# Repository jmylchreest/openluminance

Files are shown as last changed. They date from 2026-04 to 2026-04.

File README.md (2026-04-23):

# openluminance

Modular, magnetically-attached LED tiles with per-tile MCUs on a shared bus. Firmware, hardware, mechanical models, and docs live together in this repo.

**Status:** v1 design committed; 4-tile bench prototype is the next step. See [`prototypes/4-tile-bench/`](prototypes/4-tile-bench/).

---

## Concept

A master controller talks to every tile on an RS-485 bus. Each tile carries its own MCU, a small cluster of RGBW LEDs, a local buck converter, and an 8-pin palindromic edge connector so it can be rotated and still mate. The master enumerates tiles via a 1-Wire-style UID search, then pushes per-tile pixel data and broadcasts a synchronous latch.

Committed v1 decisions:

- **Per-tile MCU:** CH32V003F4P6 (32-bit RISC-V, TSSOP-20, ~£0.12, 64-bit UID baked in).
- **Bus:** RS-485 half-duplex at 1 Mbps (headroom to 10 Mbps). Linear / serpentine chain.
- **Power:** 24 V backbone chained through edge connectors, per-tile buck to 5 V. Self-correcting under voltage sag.
- **Edge connector:** 8-pin palindromic (`GND V+ A B B A V+ GND`) — any orientation mates, every signal has a redundant pin.
- **Master:** ESP32-C3 + MAX485, exposes a web UI and serves frames to the chain.

Full rationale and math in [`docs/architecture.md`](docs/architecture.md). Bench-prototype electrical schematic in [`prototypes/4-tile-bench/schematic.md`](prototypes/4-tile-bench/schematic.md).

## Repo layout

```
firmware/
  tile/            CH32V003 firmware (per tile)
  master/          ESP32-C3 master firmware
hardware/
  tile/            KiCad project for the tile PCB
  master/          KiCad project for the master board
mechanical/
  openscad/        Parametric tile enclosure, diffuser, alignment features
  stl/             Exported STLs for printing
prototypes/
  4-tile-bench/    First physical prototype — schematic, parts list, bring-up plan
docs/
  architecture.md  Bus, power, addressing, edge connector
  bom.md           Per-tile and per-system BOM
  open-questions.md Open risks and unsettled decisions
  references.md    Prior art and reference projects
thirdparty/        Git submodules for external libraries (OpenSCAD, etc.)
```

## Open questions (live)

Tracked in [`docs/open-questions.md`](docs/open-questions.md). Headline items still open:

- Edge connector physical form (pin header vs pogo strip vs mezzanine).
- Mechanical alignment tolerance on FDM PETG parts.
- Firmware update path over the bus.
- Inrush current when hot-plugging a chain of 32+ tiles at 24 V.

## Prior art

- [rmingon/led-wall](https://github.com/rmingon/led-wall) — CH32V003F*P6 + 8-bit parallel bus via 1×14 edge headers. Closest reference; hardcodes tile addresses.
- [Modular LED Wall with CH32V006 RISC-V Slave Tiles (Hackaday.io)](https://hackaday.io/project/203942-modular-led-wall-with-ch32v006-risc-v-slave-tiles)
- [CH32V003 64-bit UID read](https://pallavaggarwal.in/2023/09/25/ch32v003-programming-read-unique-id/)

## License

TBD — expected MIT for firmware/software, CERN-OHL-S for hardware, CC-BY-SA for mechanical models. Will be finalised before first release.

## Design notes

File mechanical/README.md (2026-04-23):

# mechanical/

Parametric tile enclosures, diffusers, and alignment features.

- [`openscad/`](openscad/README.md) — source `.scad` files with a preview render. Standalone; submodules in [`thirdparty/`](../thirdparty/README.md) available when needed.
- `stl/` — canonical exported STLs checked in for the current release. Iterative exports are gitignored.

Current state: **draft v0 tile model in [`openscad/tile.scad`](openscad/tile.scad)** — 100 × 100 × 15 mm single-piece enclosure. See [`openscad/README.md`](openscad/README.md) for design notes, parameters, and TODOs.

Target print material is PETG or translucent PLA. Print orientation: diffuser face down on the build plate.

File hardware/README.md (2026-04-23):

# hardware/

KiCad projects for the tile PCB and the master/bus-driver board. Empty until the bus design is frozen — see [`docs/architecture.md`](../docs/architecture.md).

- `tile/` — per-tile PCB: CH32V003, LED cluster, edge connectors, polyfuse.
- `master/` — ESP32 master or bus-driver bridge.

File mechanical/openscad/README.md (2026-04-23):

# mechanical/openscad

Parametric OpenSCAD models for the tile enclosure and associated parts.

## Files

| File | Description |
|---|---|
| [`tile.scad`](tile.scad) | Tile enclosure, draft v0. 100 × 100 × 15 mm, single-piece FDM print. |
| [`tile-preview.png`](tile-preview.png) | Rendered preview of `tile.scad` with default parameters. |

## Building

Requires OpenSCAD 2021.01 or newer.

```bash
# Render an STL for printing
openscad -o tile.stl tile.scad

# Render a preview PNG
openscad -o tile-preview.png --imgsize=1200,900 \
    --camera=50,50,7,60,0,30,400 \
    --colorscheme=Tomorrow tile.scad
```

## `tile.scad` — design notes

### Assembly structure — two printed parts (plus optional light guide)

| Part | What it is | Interchangeable? |
|---|---|---|
| **Frame** | Main body — closed back + vents, walls, edge-magnet bosses, pogo pin holes, **9 LED module cradles in a 3 × 3 grid**, **MCU dev-board retention pocket** in one corner. 100 × 100 × 13.5 mm. | No |
| **Diffuser** | 100 × 100 × 1.5 mm panel covering the entire front edge-to-edge, continuous rim press-fit into the frame opening. | **Yes** — swap for different diffusion patterns |

There is **no custom PCB** in the v1 tile. All electronics are pre-made drop-ins: 9 × SK6812 LED modules (15 × 15 mm each) slot into the cradles, and a pre-made MCU dev board (XIAO ESP32-C3, CH32V003 breakout, etc.) slides into the retention pocket. Buck + RS-485 breakout boards float in the gaps between cradles. Wiring is point-to-point with flying leads.

Render a specific part by setting `RENDER`:

```openscad
RENDER = "frame";      // or "diffuser", "assembly"
```

`assembly` shows both parts exploded along the Z axis with ghost pogo pins and colour-coded magnets — for design review, not printing.

### Print orientation

- **Frame:** closed back face down on the build plate. Walls build upward; the open front is the top of the print. Back-face vent slots print cleanly as bridged voids (first layer + in-fill around slot openings). No overhangs elsewhere.
- **Diffuser:** flat, rim side up or down either works. The rim is thin (1.2 mm) but short (3 mm) so it prints reliably in any orientation.

### How the diffuser stays on

The diffuser has a continuous rectangular rim descending from its back face that matches the frame's interior opening minus a per-side `RIM_CLEAR` (0.20 mm default). When pressed in, the rim's outer surfaces slide against the frame wall interiors along all four sides — a friction press-fit. No discrete clips to fatigue, no snap bumps, no high-stress contact points.

Assembly / service: press diffuser on from the front; to remove, insert a fingernail or plastic spudger into the `DIFF_PULL_W` (12 mm) notch cut into one edge of the diffuser and lift. The diffuser comes off clean, PCB is now accessible from the front.

| Parameter | Default | Effect |
|---|---:|---|
| `DIFFUSER_THICK` | 1.5 | Visible panel thickness |
| `RIM_DEPTH` | 3.0 | How far the rim descends into the frame |
| `RIM_T` | 1.2 | Rim wall thickness |
| `RIM_CLEAR` | 0.20 | Per-side clearance between rim outer and frame inner. **Tune this** if your printer over- or under-extrudes. Smaller = tighter; 0.05 is a very firm fit, 0.30 is loose. |
| `DIFF_PULL_W` | 12 | Finger-pry notch width |
| `DIFF_PULL_D` | 1.2 | Finger-pry notch depth |

### Coordinate system

- `z = 0` — closed back outer face (build plate when printing)
- `z = BACK_THICK` — back inner face (interior begins here)
- `z = FRAME_H` (= 13.5 mm) — top of frame walls (where diffuser rim meets the frame)
- `z = TILE_HEIGHT` (= 15 mm) — diffuser front face

Interior layout:

```
  z = 15.0  ┌─────────────── diffuser front face
  z = 13.5  ├─── diffuser back = frame wall top ───┐
                ▲                                 │
  z =  9.1  ─── ▼ LED top (SK6812 on PCB front)   │  diffuser rim
  z =  7.6  ─── PCB top face                      │  descends 3 mm
  z =  6.0  ─── PCB bottom face                   │  into frame
                ▲
  z =  2.0  ─── back inner face            ───────┘
  z =  0.0  ───────────────── back outer face (build plate)
```

### The 8-pin edge connector — all four edges populated by default

The frame cuts pogo pin holes on all four edges (`CONN_EDGES = [0, 1, 2, 3]`) so the mechanical tile is ready for v2 free-form mesh topology with no re-print. Matches the palindromic spec in [`docs/architecture.md`](../../docs/architecture.md).

```
  Reading along +X edge, low Y → high Y:
    pin 1 GND, 2 V+, 3 A, 4 B, 5 B, 6 A, 7 V+, 8 GND
```

Connector z-centre coincides with the PCB mid-plane at `CONN_Z_CENTER = 6.8`. Set `CONN_TYPE = "header"` for the bench prototype (1×8 header slot instead of individual pin holes).

### Pogo pins — short spring contacts, not deep breakouts

Tiles sit essentially wall-to-wall when mated. The pogo pins are intentionally short so the tiles don't need a gap between them — only enough length to make contact and compress ~0.5 mm per side under magnetic clamping force:

| Parameter | Default | Notes |
|---|---:|---|
| `POGO_FREE_LEN` | 5.0 mm | Uncompressed tip-to-tip |
| `POGO_COMPRESSED` | 4.0 mm | ~20 % compression when mated |
| `POGO_WALL_EXPOSE` | 0.5 mm | Tip protrusion past outer wall face at rest |
| `POGO_PIN_OD` / `POGO_FLANGE_OD` | 1.0 / 1.5 mm | Standard short-pogo format |

Sourcing: search AliExpress / LCSC for "short pogo pin 5mm 1.0mm OD" or "P50-B short spring contact". These are the same family used in pogo-pin testing jigs and magnetic breakouts.

### 24 V power rail — distributed by the PCB, not by the frame

Power is **not** a separate physical bus bar inside the frame. `V+` and `GND` pins on every populated edge tie to common `V+` / `GND` nets on the PCB — so power enters through any edge connector and exits on any other. The per-tile buck converter taps the local net.

With all four edges populated:

- **Power flows in any direction** through the tile array. No dedicated power-injection edge.
- **Chain topology on the bus** is still possible (and preferred for v1) — the PCB simply leaves `BUS_A` / `BUS_B` unrouted on 2 of the 4 edges. Frame geometry is the same.
- **v2 mesh bus** will use per-edge analogue switches (TS5A3166 or similar) under MCU control so any 2 edges can be active on the bus at a time.

### Magnets — edge-to-edge attachment

Tiles attach to adjacent tiles on the side walls. Two 5 × 2 mm neodymium discs per populated edge, offset from the edge midpoint.

| Parameter | Default | Notes |
|---|---:|---|
| `EDGE_MAGNETS` | `true` | Cut edge magnet pockets on `CONN_EDGES` |
| `EDGE_MAG_OFFSET` | 20 | mm, from edge midpoint |
| `EDGE_MAG_BOSS_D` | 3 | mm, boss extension inward from wall |
| `EDGE_MAG_Z_CENT` | 7.75 | Automatically = `(BACK_THICK + FRAME_H) / 2` |
| `MAG_CLEAR_AX` | 0.2 | Axial clearance = recess from outer face |

Pockets open outward; installed magnets recess ~0.2 mm from the tile's outer face. When two tiles mate edge-to-edge the magnet faces are separated by only ~0.4 mm of air (print clearance both sides).

**Polarity (CCW-handed rule):**

```
  +X edge   N outward at LOW Y,   S outward at HIGH Y
  +Y edge   N outward at HIGH X,  S outward at LOW X
  -X edge   N outward at HIGH Y,  S outward at LOW Y
  -Y edge   N outward at LOW X,   S outward at HIGH X
```

In `RENDER = "assembly"`, ghost magnets are colour-coded **red = N outward**, **blue = S outward**. Use this as the install reference.

### Optional back-face magnets

`BACK_MAGNETS = true` cuts four additional magnet pockets into the corner bosses, recessed from the back face. Use only if the array will stick to a ferromagnetic backplate behind the wall. Default is `false`.

### The 8-pin edge connector — matches the architecture doc

`tile.scad` models the exact palindromic 8-pin layout committed in [`docs/architecture.md`](../../docs/architecture.md). Default is `CONN_TYPE = "pogo"`, which places 8 through-holes with flange counterbores on each populated edge for double-ended pogo pins. Setting `CONN_TYPE = "header"` swaps to a single rectangular slot for a 1×8 pin header, used on the bench prototype.

Pin signal assignment (set by the PCB, not the frame — the frame is just geometry):

```
  Reading along +X edge, low Y → high Y:
    pin 1  GND
    pin 2  V+ (24 V backbone)
    pin 3  BUS_A (RS-485 A)
    pin 4  BUS_B (RS-485 B)
    pin 5  BUS_B    ← paralleled with pin 4
    pin 6  BUS_A    ← paralleled with pin 3
    pin 7  V+       ← paralleled with pin 2
    pin 8  GND      ← paralleled with pin 1
```

Palindromic. A tile flipped 180° in-plane still mates net-for-net. Every signal is carried by two pins in parallel — contact resistance halves and a single bent or oxidised pin doesn't break the link.

`CONN_EDGES` picks which edges are populated. v1 uses `[0, 2]` (= +X and −X, a linear chain). v2 sets `[0, 1, 2, 3]` and mates any edge to any edge in any orientation.

### Pogo pin spec (matches the frame cut)

Default parameters target a **double-ended spring-loaded pin, 1.0 mm OD body, 1.5 mm OD flange, 8 mm free / 5.5 mm compressed** — the common "PA1.0-8.0" format on AliExpress / LCSC. If you use a different pogo pin, update:

- `POGO_PIN_OD` — tip OD
- `POGO_PIN_HOLE` — through-hole diameter
- `POGO_FLANGE_OD` / `POGO_FLANGE_H` — flange capture counterbore
- `POGO_FREE_LEN` / `POGO_COMPRESSED` — pin length (affects tile-to-tile gap)

Render `RENDER = "assembly"` to see ghost pogo pins in their installed positions. Use this to visually verify they clear the PCB and the diffuser bay.

### Magnets — edge-to-edge attachment

Tiles attach to adjacent tiles **edge-to-edge** (not back-to-back). Edge magnets sit in the side walls of each populated edge at two positions symmetric about the edge midpoint, so that when two tiles meet along their seam the magnet faces press against each other through a thin sliver of plastic.

**Edge magnet geometry** (default 5 × 2 mm N42 neodymium discs):

| Parameter | Default | Notes |
|---|---:|---|
| `EDGE_MAGNETS` | `true` | Cut edge magnet pockets on `CONN_EDGES` |
| `EDGE_MAG_OFFSET` | 20 | mm, magnet centre from edge midpoint (one above, one below) |
| `EDGE_MAG_BOSS_D` | 3 | mm, how far the interior reinforcement boss sticks in from the wall |
| `EDGE_MAG_BOSS_W` | 9 | mm, Y-extent of each boss (> MAG_OD for margin) |
| `EDGE_MAG_BOSS_H` | 8 | mm, Z-extent (only in the back half of the tile, so PCB doesn't need cutouts) |
| `MAG_OD` | 5 | Magnet OD |
| `MAG_H` | 2 | Magnet thickness |
| `MAG_CLEAR_RAD` | 0.15 | Radial print clearance per side |
| `MAG_CLEAR_AX` | 0.2 | Axial clearance — also the recess from the outer face |

Pockets open **outward** so magnet faces are separated by only ~0.4 mm of print-clearance air when two tiles meet (MAG_CLEAR_AX × 2). Holding force is close to the "magnets touching" maximum. Plenty of boss material behind the pocket floor for structural strength.

**Polarity — use the CCW-handed pattern:**

```
Traversing edges counter-clockwise around the tile:
   +X edge    N outward at LOW Y,   S outward at HIGH Y
   +Y edge    N outward at HIGH X,  S outward at LOW X
   -X edge    N outward at HIGH Y,  S outward at LOW Y
   -Y edge    N outward at LOW X,   S outward at HIGH X
```

With this rule, any edge pair mating in any orientation pairs N↔S automatically. A 180° in-plane rotation of one tile swaps the magnet positions but also swaps the polarities on each edge, so mating still works.

In the `RENDER = "assembly"` view, ghost magnets are colour-coded: **red = N outward**, **blue = S outward**. Use this as an install reference.

### Optional back-face magnets

`BACK_MAGNETS = true` turns on the original back-face magnet pockets — one per corner boss, recessed from the back face. Use these **only** if you want the assembled tile to stick to a ferromagnetic backplate behind the wall (e.g. a steel sheet). They are **not required** for normal operation; edge magnets hold adjacent tiles together, and the array mounts to the wall via screws through the corner bosses or via a separate mounting rail. Default is `false`.

### Diffuser retention

Four clips on the frame interior (two per long wall) protrude 0.8 mm into the diffuser bay. The diffuser snaps past them during install and is held against the lip above. A 12 mm finger-pull slot on one edge of the diffuser lets it be popped out with a fingernail or spudger when swapping variants.

### Frequently-tweaked parameters

| Parameter | Default | Effect |
|---|---:|---|
| `TILE_SIZE` | 100 | Square footprint |
| `TILE_HEIGHT` | 15 | Overall Z |
| `WALL_THICK` | 2 | Side walls |
| `LIP_WIDTH` | 4 | Perimeter lip that retains the diffuser (inward from walls) |
| `LIP_THICK` | 1.5 | Front lip thickness (visible perimeter frame) |
| `DIFFUSER_THICK` | 1.5 | Diffuser panel thickness |
| `PCB_BAY_D` | 4 | Gap between diffuser back and PCB top — LED height budget |
| `BACK_CAP_THICK` | 2 | Rear cover thickness |
| `CORNER_BOSS_XY` | 14 | Size of corner post (carries magnet + PCB screw) |
| `MAG_INSET` | 8 | Magnet pocket centre from tile corner |
| `CONN_TYPE` | `"pogo"` | `"pogo"` or `"header"` |
| `CONN_EDGES` | `[0, 2]` | Which edges are populated |

### Known issues / TODO

- **Palindromic PCB layout not yet drawn.** The SCAD file reserves the geometry; the KiCad layout in `hardware/tile/` will assign nets per the table above.
- **Pogo pin retention assumes insertion from the inside face** before the PCB is installed. If a different pin type is used (e.g. single-ended sleeve-mounted to the PCB), the frame cuts need `_pogo_one_cut` updated.
- **Inter-tile alignment dowels** are not yet modelled. Currently the mating is positioned by the pogo pin tips + corner magnets. For >4 tiles chained, a pair of 1 mm alignment posts on each edge will reduce accumulated misalignment. Reserved for v0.3.
- **Ventilation** is on the back cap only. Side-wall vents may be needed once thermals are measured on the bench.
- **No cable passthrough** for a dedicated 24 V power injection tile. A tile variant with a screw-terminal cutout is a v1 job.
- **No orientation indicator on the diffuser.** If the diffuser is directional (e.g. pixelated), add an alignment notch that matches one on the frame.

## Library availability

The [`thirdparty/`](../../thirdparty/README.md) submodules (BOSL2, NopSCADlib, Round-Anything, threadlib) are available if needed. `tile.scad` is intentionally dependency-free in v0.x for easy review. Later versions will use BOSL2 for rounded fillets and NopSCADlib's pogo pin / PCB primitives.

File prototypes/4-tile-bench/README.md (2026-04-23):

# 4-tile bench prototype

First physical prototype. Goal is to prove the v1 electrical and protocol design end-to-end on a breadboard / perfboard before committing to a PCB.

## Scope

- 4 tiles assembled, bench parts for 8 in stock (slack for failures and iteration).
- Real 24 V PSU, real RS-485 wiring between tiles.
- Linear chain topology (master → tile 1 → tile 2 → tile 3 → tile 4).
- Discovery, addressing, pixel push, full-frame latch verified.

## Contents

- [`schematic.md`](schematic.md) — electrical diagrams, netlist, component-level detail.
- [`parts-list.md`](parts-list.md) — exact part numbers with supplier references.
- [`bringup-checklist.md`](bringup-checklist.md) — step-by-step verification plan.

## Success criteria

The prototype is successful when all of these pass:

1. **Power:** 4 tiles chained, measured 24 V rail sag at tile 4 is < 0.3 V at worst-case brightness. 5 V local buck output stays within ±2 % under full LED load.
2. **Bus integrity:** RS-485 eye diagram at tile 4 is clean at 1 Mbps. Sustained zero-error packet stream for 10 minutes at 60 fps-equivalent load.
3. **Discovery:** All 4 UIDs enumerated and addressed within 1 s from cold boot. Reproducible across 10 cold starts.
4. **Frame push:** Full 4-tile frame (25 RGBW pixels each) delivered and latched in < 20 ms. No visible tearing between tiles during animation.
5. **Fault tolerance:** Shorting the 5 V output on one tile (simulated LED short) blows only that tile's polyfuse; the other three continue operating.
6. **Thermal:** Tiles at full white for 30 minutes stay below 60 °C surface temperature with passive convection.

Failures on any of these invalidate the design assumption and must be resolved before PCB order.

## What this prototype does NOT test

- Mechanical edge connector (bench uses flying leads; connector choice is tested separately).
- Final PCB routing and ground-pour EMI.
- Scaling beyond 4 tiles (covered later with a 16-tile run on PCB).
- Free-form mesh v2.

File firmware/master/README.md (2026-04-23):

# firmware/master

Master controller firmware (ESP32).

Not yet implemented. Target responsibilities:

- Discover tiles on the bus, assign addresses, collect UIDs
- Hold the topology map (manual in v1, neighbour-derived in v2)
- Accept frame data from upstream (custom API, WLED integration, or DDP/E1.31 bridge)
- Slice frames into per-tile pixel payloads and push them over the bus
- Serve a web UI for manual tile placement and system control

Framework TBD. Likely ESP-IDF or Arduino-ESP32 depending on whether we fork WLED or build fresh.

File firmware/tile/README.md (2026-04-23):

# firmware/tile

Per-tile firmware for the CH32V003.

Not yet implemented. Target responsibilities:

- Read 64-bit UID at boot
- Listen on the bus for addressed packets (SOF / ADDR / CMD / LEN / PAYLOAD / CRC8)
- Respond to discovery broadcasts
- Drive the local LED strip
- Report neighbour-pin state on request (v2)

Toolchain target: [ch32v003fun](https://github.com/cnlohr/ch32v003fun) or PlatformIO with the CH32V platform. Decide once the bus design is frozen.

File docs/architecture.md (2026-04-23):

# Architecture — v1

This is the committed v1 direction. The original 8-bit-parallel sketch is retained in the appendix for context. v2 (free-form 2D mesh) is deferred — see [`open-questions.md`](open-questions.md).

## Summary

- **Topology:** linear / serpentine chain (tiles connect on two opposing edges).
- **Signal bus:** RS-485 multidrop, half-duplex, 1 Mbps (headroom to 10 Mbps).
- **Power backbone:** 24 V DC, chained through connectors, regulated locally on each tile.
- **Per-tile MCU:** CH32V003F4P6 (TSSOP-20).
- **LEDs:** 25 × SK6812 RGBW per tile, 5 V, driven from the local buck output.
- **Discovery:** UID-based enumeration using a 1-Wire-style binary-tree search, adapted for RS-485.
- **Master:** ESP32-C3 with an RS-485 transceiver; web UI holds the tile map.

## System block diagram

```
  24V PSU
     │
     ▼
┌────────────┐    ┌───────┐    ┌───────┐          ┌───────┐
│  MASTER    │────│ Tile  │────│ Tile  │── ... ──│ Tile  │
│ ESP32-C3   │    │   1   │    │   2   │          │   N   │
│ + MAX485   │    └───────┘    └───────┘          └───────┘
│ + 120Ω     │                                     + 120Ω
│   term     │                                    (end term)
└────────────┘
     │
     ▼
    Wi-Fi / Web UI
```

Master and the last tile are the two RS-485 bus endpoints; both carry 120 Ω termination. Middle tiles leave termination unpopulated. Power and signal share the same edge connectors.

## Why this stack (vs. the original parallel-bus sketch)

| Concern | Parallel bus (original) | RS-485 + 24 V (this) |
|---|---|---|
| Pins per edge | 14 | **8 (palindromic, redundant)** |
| Signal integrity over chained connectors | Poor (skew, reflections) | **Excellent (differential, proven at DMX scale)** |
| Power distribution | 5 V chained → unusable past ~4 tiles | **24 V chained, local buck — scales to 32+ tiles** |
| Protocol maturity | Novel / hand-rolled | **RS-485 is 40+ years proven, DMX is literally this** |
| Auto-addressing | Unproven on parallel bus | **1-Wire binary search adapted — well-understood** |
| Bill of materials | Underestimated pogo pin cost | Realistic, slightly higher per tile but viable |
| EMI | Significant (48 MHz parallel across gaps) | Low (differential, slow edges) |

## Edge connector — 8-pin palindromic

Pinout reads identically forwards and backwards. This means any two edges mate correctly in either relative orientation — a tile can be flipped end-for-end in-plane and still connect. Every signal is carried by two pins in parallel, so contact resistance halves and single-pin failures don't break the link.

| Pin | Name | Purpose |
|---:|---|---|
| 1 | GND | Return |
| 2 | V+ | 24 V backbone |
| 3 | BUS_A | RS-485 differential A |
| 4 | BUS_B | RS-485 differential B |
| 5 | BUS_B | RS-485 differential B (paralleled — same net as pin 4) |
| 6 | BUS_A | RS-485 differential A (paralleled — same net as pin 3) |
| 7 | V+ | 24 V backbone (paralleled — same net as pin 2) |
| 8 | GND | Return (paralleled — same net as pin 1) |

Pass-through on the tile: `V+` and `GND` wire straight across from one edge connector to the other — no series element — so downstream tiles get full rail. The local circuit taps via a polyfuse into the buck converter. Both edges share the same `BUS_A` and `BUS_B` nets (RS-485 multidrop).

### Rotational invariance — v1 vs v2

- **v1:** populate this 8-pin connector on the two chain edges only. Gives 180° in-plane flip tolerance for chain mating. Leave the other two edges unpopulated.
- **v2:** populate the same 8-pin connector on all four edges, all wired to the same V+/GND/BUS nets. Now any tile can mate any other tile on any edge in any orientation, BUT the bus becomes a mesh — need per-edge analogue switches (e.g. TS5A3166) selected by the MCU so only two edges are electrically active on the bus at any time. **Mechanical connector is identical between v1 and v2**, so v2 upgrade is a firmware-plus-populate change, no PCB redesign.

Face-flip (LEDs pointing at the wall) is prevented mechanically — magnet polarity + asymmetric alignment dowels on the back face only.

## Per-tile electrical overview

```
                            ┌──────────────────────────────────┐
  LEFT EDGE                  │              TILE               │        RIGHT EDGE
  CONNECTOR                  │                                 │        CONNECTOR
                             │                                 │
  V+ ──────┬──────────────── pass-through rail ─────────────────┬──── V+
  GND ─────┼──────────────── pass-through rail ─────────────────┼──── GND
           │                 │                                 │      │
           │  ┌──────────────┴─────┐                           │      │
           │  │ Polyfuse (0.5A)    │                           │      │
           │  │ → P-MOSFET (rev)   │                           │      │
           │  │ → TVS diode        │                           │      │
           │  │ → Buck (24→5V, 2A) │                           │      │
           │  └────────┬───────────┘                           │      │
           │           │ 5V                                    │      │
           │           ├────────────────┬──────────┐           │      │
           │           │                │          │           │      │
           │           ▼                ▼          ▼           │      │
           │     ┌──────────┐    ┌──────────┐  ┌─────────┐     │      │
           │     │ CH32V003 │    │  MAX485  │  │ 25× SK- │     │      │
           │     │  MCU     │────│ RS-485   │  │  6812   │     │      │
           │     │          │    │  TRX     │  │ RGBW    │     │      │
           │     └────┬─────┘    └────┬─────┘  └─────────┘     │      │
           │          │               │                        │      │
           │          │          ┌────┴────┐                   │      │
  BUS_A ───┼──────────┼──────────┤ A     B ├───────────────────┼── BUS_A
  BUS_B ───┼──────────┼──────────┤         ├───────────────────┼── BUS_B
           │          │          └─────────┘                   │      │
           │          │                                        │      │
           │          └── UART TX/RX + DE/nRE                  │      │
           │                                                   │      │
           └───────────────────────────────────────────────────┘
```

## Addressing protocol (v1)

Half-duplex RS-485. Master polls; tiles respond only when addressed or during a discovery slot.

**Discovery (binary-tree UID search)** — adapted from Dallas 1-Wire:

1. Master broadcasts `SEARCH_ROM(prefix, length)`.
2. All tiles whose 64-bit UID starts with `prefix` respond on the next bit position: `0`, `1`, or both (collision).
3. Collision → master descends one branch (say `0`), recurses.
4. When a leaf is reached, master has a unique UID → assigns it a bus address (1..254).

For N tiles this is O(N × 64) bus transactions — about 2 seconds for 32 tiles at 1 Mbps. Runs once at startup, never again unless the map is rebuilt.

**Normal operation:**

```
  Packet: 0xA5  ADDR  CMD  LEN  PAYLOAD[LEN]  CRC8
          SOF   1B    1B   1B   0..240B       1B
```

- `ADDR 0x00` = master
- `ADDR 0xFF` = broadcast
- `ADDR 0x01..0xFE` = unicast
- Commands: `PING`, `SET_PIXELS`, `LATCH`, `GET_STATUS`, `REBOOT`, `SET_ADDR` (during discovery only)

Frame flow: master sends `SET_PIXELS` to each tile in turn (75 bytes RGB × 25 pixels + overhead ≈ 80 bytes per tile → 0.8 ms per tile at 1 Mbps). Then a single `LATCH` broadcast tells everyone to update simultaneously. 32 tiles = 25.6 ms + 1 latch = ~27 ms, comfortably inside a 60 fps budget.

## Power math (why 24 V)

Per tile worst case: 9 LEDs × 60 mA @ full white = 540 mA @ 5 V = 2.7 W. 32-tile array = 86 W. (The original 25-LED design pushed 7.5 W/tile / 240 W system; the tile is a lighting element, not a pixel-addressable display, so 9 LEDs is plenty and the numbers shrink.)

At **5 V** chained: tile 1 carries 17 A. Pogo/header contacts can't carry that across many tiles without significant IR drop — LEDs go dim and off-colour down-chain.

At **24 V** chained with per-tile buck (η ≈ 85 %): tile 1 carries ~4.3 A across the whole 32-tile chain, drop per hop ≈ 0.1 V. Buck compensates by drawing slightly more current as input sags. **Self-correcting**.

System PSU: 24 V, **≥5 A** for 32 tiles (with margin). Mean Well LRS-100-24 or equivalent (~£15).

## Components per tile (high level)

| Function | Part | Est. £ (vol) |
|---|---|---:|
| MCU | CH32V003F4P6 (TSSOP-20) | 0.12 |
| RS-485 transceiver | MAX485 / SP485EEN / MAX3485 | 0.35 |
| Buck converter (24→5 V) | MP1584EN + L + Cs (discrete) | 0.60 |
| LEDs | 9 × SK6812 RGBW (3 × 3 grid, 30 mm pitch) | 1.53 |
| Protection | Polyfuse + TVS + rev-pol FET | 0.25 |
| Edge connectors | 2× pin header or pogo strip | 0.80 |
| PCB + passives | | 0.40 |
| Enclosure + diffuser + magnets | | 0.80 |
| **Total** | | **~£5.31** |

Detailed part numbers in [`../prototypes/4-tile-bench/parts-list.md`](../prototypes/4-tile-bench/parts-list.md).

## Appendix — discarded: 8-bit parallel bus

The original proposal used DATA0–7, CLK, EN on a 14-pin edge connector with tile addresses hardcoded in `main.c`. Discarded because: (a) signal integrity across chained connectors at 48 MHz is unpredictable, (b) pin count drives connector cost and mechanical failure rate, (c) no native arbitration means auto-addressing requires inventing a scheme, (d) EMI risk for any future compliance work. The reference project ([rmingon/led-wall](https://github.com/rmingon/led-wall)) is a working existence proof of that architecture at small scale but does not auto-address. RS-485 gives us equivalent or better bandwidth with 6 pins, proven protocol stacks, and off-the-shelf transceivers.

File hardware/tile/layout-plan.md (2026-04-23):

# Tile PCB layout plan

How the LED array, MCU, buck, transceiver, and supporting components fit inside the 100 × 100 × 15 mm enclosure. Companion to [`../../mechanical/openscad/tile.scad`](../../mechanical/openscad/tile.scad) and [`../../docs/architecture.md`](../../docs/architecture.md). Drives the KiCad board outline before the first schematic spin.

## Topology: no custom PCB — drop-in modules + pre-made dev board

**Nothing is custom-fabricated.** Nine individual pre-made SK6812 LED modules drop into 9 cradles printed into the frame interior at the 3 × 3 grid positions. A pre-made MCU dev board (XIAO ESP32-C3, CH32V003 breakout, or equivalent) slides into a retention-rib pocket in the −X, −Y corner of the frame. Short point-to-point wires connect the dev board to each LED module (data chain + power) and to each edge-connector group. No custom PCB; no central board; no corner screw bosses.

```
   ┌──────────────────────────────┐ ← diffuser (100 × 100, edge-to-edge)
   │                              │
   │                              │
   │  (LED) (LED) (LED)           │ ← 9 × SK6812 modules in 3 × 3 cradles
   │                              │     on 30 mm pitch, printed into frame
   │  (LED) (LED) (LED)           │
   │                              │
   │  (LED) (LED) (LED)           │
   │                              │
   ├──────────────────────────────┤
   │ [dev brd]                    │ ← MCU dev board in its corner pocket,
   │                              │     retained by printed rib clips.
   │                              │     Wires fan out to LED cradles and
   │                              │     to the edge connector groups.
   ├──────────────────────────────┤ ← frame back inner face
   │     vvv     vvv     vvv      │ ← vent slots
   └──────────────────────────────┘ ← frame back outer face
```

### Why no PCB

- **Lower iteration cost.** No board spin, no JLCPCB wait time. Pick a different MCU next week — swap the dev board.
- **No SMT assembly.** All parts come pre-assembled. Per-tile build is soldering wires to header pins.
- **Simpler v1 bench.** Any CH32V003 dev board + MP1584 buck module + MAX485 breakout wired together works; or a XIAO ESP32-C3 on its own if you're willing to take the WiFi-per-tile path.
- **Repairability.** Dead LED? Pop the diffuser, pull the module, plug in a new one. Dead MCU? Slide the dev board out of its pocket and replace.

### Trade-off

Per-tile assembly is **slower and more expensive** than a custom PCB would be (~£18 + ~30 min of wiring vs ~£5 + 10 min of click-and-solder). This is the right choice for exploratory v1 bench hardware, not for a production run — at volume, collapse back into a custom PCB.

## Space budget — what's actually available

### Z stack (15 mm total, 11.5 mm interior)

```
  z = 15.0 ────────── diffuser front face ──────────
  z = 13.5 ────────── frame walls top / diffuser back
                 ↑
                 │ 4.4 mm diffusion gap (air)
                 ↓
  z =  9.1 ────────── LED top (SK6812 body 1.5 mm above PCB)
  z =  7.6 ────────── PCB top face ──── [ 9 × SK6812 in 3×3 grid ]
  z =  6.0 ────────── PCB bottom face ── [ MCU, buck, transceiver, passives ]
                 ↑
                 │ 4.0 mm back-side component space
                 ↓
  z =  2.0 ────────── back inner face
  z =  0.0 ────────── back outer face (ventilation slots)
```

**Tight constraint: the 4 mm back-side space.** Any component taller than 4 mm doesn't fit. This rules out standard radial electrolytic caps (~11 mm tall) and some through-hole inductors. See [BOM constraints](#component-height-constraints) below.

### Plan view — 100 × 100 mm interior features

Features that cut into the 96 × 96 mm usable interior footprint:

| Feature | Footprint | Qty | Area | Notes |
|---|---|---:|---:|---|
| LED module cradles | 17.4 × 17.4 mm | 9 | 2725 mm² | 15 × 15 mm module bay with 1.2 mm lip, z = 2 → 6 |
| MCU board pocket (floor + ribs) | 26 × 20 mm | 1 | 520 mm² | Corner at (3, 3) with rib clips on ±Y sides |
| Edge magnet bosses | 9 × 3 mm | 8 | 216 mm² | 2 per edge × 4 edges |
| Pogo pin retainers | 22 × 2 mm | 4 | 176 mm² | 1 strip per edge, centred |
| **Total feature area** | | | **~3640 mm²** | out of 9 216 mm² interior |

There's no longer a PCB footprint to negotiate — all these features are just printed plastic that the modules/board drop into. Remaining interior volume is for wire routing.

## Layout — plan view

No board outline to draw — the features are printed directly into the frame. Plan view (not to scale):

```
           -Y edge
           ▼
  ┌──────────────────────────────┐ ← 100 mm tile outer edge
  │                              │
  │ [MCU]                        │
  │ pocket    ┌─┐  ┌─┐  ┌─┐      │   3 × 3 LED cradles (17.4 mm each)
  │ (26×20)   └─┘  └─┘  └─┘      │   centred at tile-local
  │           ┌─┐  ┌─┐  ┌─┐      │   (20, 20), (50, 20), (80, 20),
  │           └─┘  └─┘  └─┘      │   (20, 50), (50, 50), (80, 50),
  │           ┌─┐  ┌─┐  ┌─┐      │   (20, 80), (50, 80), (80, 80)
  │           └─┘  └─┘  └─┘      │
  │                              │
  └──────────────────────────────┘
```

### LED cradle dimensions

Each cradle is a 17.4 × 17.4 mm printed plinth with a 1.2 mm lip around the top. The 15 × 15 × 1.6 mm LED module drops into the centre recess (friction fit, no glue). A 3 mm wire-exit slot on the −Y face of each cradle lets the pigtail escape to the harness.

Typical SK6812 single-LED module footprints (confirm before buying):

| Source | Outer size | Notes |
|---|---|---|
| BTF-Lighting individual SK6812 PCB | ~15 × 15 mm | Solder pads on all 4 sides |
| Adafruit NeoPixel single (1558) | ~8 × 10 mm | Smaller; would need adapter plate or smaller cradle |
| Custom bare SK6812 5050 on a 15 × 15 breakout | 15 × 15 mm | ~£0.15 at JLCPCB with 500 MOQ — still no *per-tile* custom board, just a reusable sub-module |

If your modules are smaller than 15 × 15, reduce `LED_MOD_XY` in `tile.scad`; the cradle auto-sizes.

### MCU board pocket

Floor at the frame back inner face, in the −X, −Y corner. Two parallel printed ribs (1.2 mm × 3 mm tall) retain the board by clamping its long sides. Works for any board up to 24 × 18 mm or so — covers the common dev boards:

| Board | Size | Notes |
|---|---|---|
| Seeed XIAO ESP32-C3 | 21 × 17.5 mm | USB-C, WiFi + BT. Overkill but plug-and-play |
| Seeed XIAO RP2040 / RP2350 | 21 × 17.5 mm | No WiFi, great for RS-485 node |
| CH32V003F4P6 bare breakout (hand-made or LCSC) | ~20 × 15 mm | Matches the committed architecture |
| RP2040-Zero | 23 × 18 mm | Cheap (~£3), USB-C, loads of GPIO |

## LED grid placement

**Nine** SK6812 RGBW modules at 30 mm pitch, centred in the tile: positions (20, 20), (50, 20), (80, 20), (20, 50), (50, 50), (80, 50), (20, 80), (50, 80), (80, 80). Each module sits in its own printed cradle; the centre cradle also acts as a thermal conduit from the centre LED down into the frame back.

Data chain: WS2812-style serpentine — row 0 left→right, row 1 right→left, row 2 left→right. DIN of LED (20, 20) from MCU (e.g. ESP32-C3 GPIO0); DOUT of LED (80, 80) terminated at a header pin on the MCU board for debug.

### Why 9, not 25

Each tile is **one colour cell in the system**, not a pixel-addressable display. Nine SK6812 RGBW at 60 mA = ~540 mA @ 5 V = 2.7 W peak per tile, ~45 lumens of diffused ambient output. The diffuser blends them into a single uniform glow (or 9 distinct pixels if the optional light guide is fitted). Going to 25 triples the power, cost, and thermal load for no benefit if the tile isn't trying to draw an image.

## Controller stack per tile

Three pre-made modules wired together, sitting in the MCU pocket + routed to the edge connectors via a harness:

1. **MCU dev board** — carries the CH32V003 (or ESP32-C3, etc.) and exposes its GPIOs on 2.54 mm headers. Sits in the corner pocket.
2. **Buck converter module** — MP1584EN 24 → 5 V, ~17 × 11 × 4 mm. Pre-trimmed to 5 V output. Mounts anywhere with double-sided tape; its output supplies the dev board and LED string.
3. **RS-485 transceiver breakout** — MAX485 on a tiny carrier with header pins. ~15 × 15 mm. Wired between the MCU's USART and the BUS_A/BUS_B edge pins.

Total controller footprint: ~55 × 20 mm when laid end-to-end, plus some wiring space. Fits comfortably in the bottom half of the tile interior (between the LED cradles and the back wall), held by double-sided tape. The MCU pocket holds only the MCU board; buck and transceiver float in the interior.

### Height budget

Interior depth from back inner face (z = 2) to lowest LED cradle surface (z = 2) is 0 — the cradles *start* at the back inner face. So the buck/transceiver modules sit in the gaps between cradles, not underneath them. Max module height = cradle top − back face = 4 mm. MP1584 modules are ~4 mm including header pin stubs (trim stubs flush if necessary). RS-485 breakouts are typically 3 mm. Both fit.

Alternative: mount buck + transceiver to the inside of the back cap or the underside of the diffuser... no, neither of those is accessible. They live in the interior floor between cradles.

## LEDs are not strips

Individual SMD SK6812 5050 parts placed directly on the tile PCB, not a flexible strip. Three reasons:

1. **Pitch mismatch.** 60 LED/m strip has 16.7 mm pitch; our grid needs 20 mm. Re-cutting and re-wiring a strip to 25 segments is fragile and time-consuming.
2. **Fewer parts, fewer joints.** The PCB is already being made for the MCU and supporting circuitry. Placing 25 more LEDs on the same board is near-free at JLCPCB (~1 ¢ per placement).
3. **Thickness.** Strip form factor adds ~1 mm for the strip PCB plus adhesive plus any sleeving. The SMD LEDs sit flat on our board with no extra stack-up.

If you ever want to adapt the design to strips, the control electronics would need to split onto a separate small MCU board at one end of the strip run.

## Optional light guide

A third printable part — a 5 × 5 pixel-grid lattice — can be printed separately and dropped into the tile between the PCB and the diffuser. With it, each LED has its own 20 × 20 mm chamber with reflective walls, producing sharp distinct pixels. Without it, light blends smoothly across the diffuser.

Specs (see [`../../mechanical/openscad/tile.scad`](../../mechanical/openscad/tile.scad) — `RENDER = "light_guide"`):

- 5 × 5 grid of 20 × 20 mm cells
- Wall thickness 1.2 mm, wall height 5 mm
- Outer footprint ≈ 95 × 95 mm (sits inside the frame opening with 0.4 mm per-side clearance)
- Material: white PETG or PLA (reflective)
- No retention features — held in place by the PCB below and the diffuser rim above
- Swappable without disassembling the frame: pop the diffuser, drop the guide in, re-seat the diffuser

Print orientation: flat. Walls print as tall thin columns; use 2–3 perimeters for wall strength.

## Routing summary

High-level PCB wiring plan for the v1 (linear-chain) variant:

| Net | Where | Notes |
|---|---|---|
| `V+` (24 V) | From +X and −X edge connectors (pin 2 and pin 7) → common net → local buck input | Tie +Y and −Y V+ pads to the same net for v2 compatibility |
| `GND` | From all four edge connectors (pins 1 and 8) → common ground plane | Thick copper pour on inner layers |
| `5V` (local) | Buck output → MCU, MAX485, and the 25-LED array | Local to this tile; does not leave |
| `BUS_A` / `BUS_B` | +X edge (pins 3, 6 and 4, 5) ↔ MAX485 A/B ↔ −X edge | +Y and −Y bus pads left unconnected in v1 |
| `LED_DATA` | MCU PA1 → 330 Ω series R → DIN of first LED → DOUT→DIN chain through all 25 → final DOUT to test pad | Serpentine route |
| `UART_TX` / `UART_RX` / `DE` | MCU USART1 + one GPIO → MAX485 control pins | Keep short |

## Build constraints (for the assembly person)

- **MCU board** fits a pocket 26 × 20 mm at tile-local (3, 3) – (29, 23), retained by 1.2 mm ribs on ±Y long sides. Boards up to 24 × 18 mm work.
- **9 LED modules** drop into cradles on 30 mm pitch centred at tile-local (20, 20) through (80, 80). Each cradle bay is 15 × 15 mm with a 1.2 mm lip — pre-made 15 × 15 mm SK6812 breakouts are the target fit. Smaller modules (e.g. 8 × 10 mm) need either a smaller `LED_MOD_XY` in the SCAD or a printed adapter plate.
- **Pogo pin tips** are at z = 6.8 on every populated edge. Wire the module's edge-pad pigtails to each pin's inner tip — 32 pins per tile is a lot of hand-soldering; an edge-breakout mini-PCB (pre-made or custom) makes this tractable. Kept out of the SCAD for v1; pure flying-lead assembly works for the bench prototype.
- **Max interior component height** (for buck, transceiver, wire bundles) between the back wall and the underside of the LED cradles = 4 mm. MP1584 modules fit with trimmed header pins; RS-485 breakouts fit easily.
- **Thermal:** 9 LEDs × 60 mA @ 5 V = 2.7 W peak per tile. Passive convection via back-face vents handles this; no heat sinks or thermal grease needed.

## Open questions for the PCB design stage

- **Pogo pin mounting:** pins mounted to the frame (currently modelled) or soldered to PCB edge castellations? Choice affects PCB edge-pad vs. edge-castellation design.
- **Power injection:** do we need a dedicated tile variant with a screw-terminal 24 V input for the head of a long chain? Or inject via a custom master-adjacent tile?
- **Firmware update path:** expose SWIO via a 3-pin test pad on the back of the PCB, accessible through the back-face vent area with a pogo jig. Needs space reservation.

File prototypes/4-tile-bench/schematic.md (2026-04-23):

# Electrical Schematic — 4-tile bench

Text schematic for the bench prototype. A proper KiCad schematic will land in `hardware/tile/` before PCB order; this document captures the design the KiCad sheets should implement and is the source of truth for the bench build.

## 1. System-level

```
   ┌─────────────┐
   │  24 V PSU   │   Mean Well LRS-50-24 or equivalent
   │   (2 A +)   │
   └──┬──────┬───┘
      │ 24V  │ GND
      ▼      ▼
   ┌──────────────┐
   │   MASTER     │
   │              │
   │  ESP32-C3    │       ┌───────┐   ┌───────┐   ┌───────┐   ┌───────┐
   │  + MAX485    │──A────│       │───│       │───│       │───│       │
   │  + 120Ω term │──B────│ Tile  │───│ Tile  │───│ Tile  │───│ Tile  │
   │  + biasing   │──V+───│  #1   │───│  #2   │───│  #3   │───│  #4   │
   │  680Ω x2     │──GND──│       │───│       │───│       │───│       │
   │              │       └───────┘   └───────┘   └───────┘   └───┬───┘
   └──────┬───────┘                                                │
          │                                                  120Ω termination
          ▼                                                  between A and B
        Wi-Fi                                                  on last tile
```

Master carries the `+` end of the RS-485 bus, fixed biasing (680 Ω A→V+, 680 Ω B→GND), and one 120 Ω termination. The fourth tile carries the other 120 Ω. Middle tiles leave termination and biasing unpopulated.

## 2. Per-tile block diagram

```
        LEFT EDGE                                           RIGHT EDGE
        CONNECTOR J1                                        CONNECTOR J2
        ┌────────┐                                          ┌────────┐
 GND ───│ 1      │◄────────── pass-through rail ───────────►│  1   8 │─── GND
  V+ ───│ 2  PIN │                                          │  PIN 7 │─── V+
 A   ───│ 3  MAP │◄────────── shared bus net A ────────────►│  MAP 6 │─── A
 B   ───│ 4      │◄────────── shared bus net B ────────────►│      5 │─── B
 B   ───│ 5      │                                          │      4 │─── B
 A   ───│ 6      │                                          │      3 │─── A
  V+ ───│ 7      │                                          │      2 │─── V+
 GND ───│ 8      │                                          │      1 │─── GND
        └────────┘                                          └────────┘
            │                                                    │
            │                                                    │
            │  (V+ and GND pass straight across — no series element)
            │
            ├───────────────────────────────────────── local 24V tap
            │
            ▼
      ┌─────────────┐
      │ POLYFUSE    │ 0.5 A hold, 1 A trip
      │ (F1)        │
      └─────┬───────┘
            ▼
      ┌─────────────┐
      │ P-MOSFET    │ Reverse-polarity block
      │ (Q1)        │
      └─────┬───────┘
            ▼
      ┌─────────────┐
      │ TVS (D1)    │ SMBJ28CA bidirectional, 28 V clamp
      └─────┬───────┘
            ▼
      ┌─────────────┐
      │ 47 µF/35V   │ Bulk input cap (C1)
      │ + 100 nF    │ HF bypass (C2)
      └─────┬───────┘
            ▼
      ┌─────────────┐   L1: 22 µH shielded
      │ MP1584EN    │   D2: SS34 Schottky
      │ buck (U1)   │   R_FB: 10k / 3.16k → 5.0 V out
      │ 24V → 5V    │   C_OUT: 2× 22 µF X7R
      └─────┬───────┘
            │ 5 V local
            ├─────────────────┬───────────────────┐
            ▼                 ▼                   ▼
       ┌────────┐        ┌─────────┐      ┌──────────────┐
       │ CH32V- │        │ MAX485  │      │ 25 × SK6812  │
       │  003   │──TX───►│ DI      │      │  RGBW chain  │
       │  (U2)  │◄─RX────│ RO      │      │              │
       │        │──DE───►│ DE/RE'  │      │ DATA_IN ◄────┼── from U2 PA1
       │        │        │ A   B   │      │              │
       └────────┘        └──┬───┬──┘      └──────────────┘
                            │   │
                      SHARED BUS NET A/B
                      (tied to both J1 and J2
                       pins via identical PCB nets)
```

## 3. Power subsystem detail

```
Edge V+ (24 V) ──┬────────────────────────────────────── pass-through to other edge V+
                 │
                 ├── F1 ──┬── Q1_s     Q1 = AO3401 P-MOSFET
                 │        │            gate to GND via R_G (10k), diode-clamped
                 │        │            source faces load (blocks reverse polarity
                 │        │            and drops only ~Rds_on × I ≈ 50 mV)
                 │        │
                 │        └── drain ──┬── TVS (D1, SMBJ28CA) to GND
                 │                    │
                 │                    ├── C1 (47 µF/35 V) to GND
                 │                    │
                 │                    └── VIN of MP1584
                 │
Edge GND ────────┴────────────────────────────────────── pass-through to other edge GND

MP1584EN (U1) pinout (TSOT-23-8):
   1 BOOT  ── 10 nF to SW
   2 VIN   ── from Q1 drain
   3 EN    ── tied to VIN (always on)
   4 COMP  ── loop compensation RC (22 kΩ + 2.2 nF to GND)
   5 FB    ── 3.16 kΩ to GND, 10 kΩ to VOUT  (Vfb = 0.8 V, ratio → 5.0 V)
   6 GND
   7 SW    ── to L1 (22 µH) → VOUT node; D2 (SS34) from SW to GND
   8 VIN   ── tied to pin 2

VOUT node:
   ── 2 × 22 µF X7R (C_OUT1, C_OUT2) to GND
   ── 100 nF (C_OUT3) to GND at point of load
   ── 5 V rail to MCU, transceiver, LED cluster
```

### Power math check

| Load | I @ 5 V | Local 5 V current |
|---|---:|---:|
| CH32V003 active | ~5 mA | |
| MAX485 active | ~1 mA | |
| 25 × SK6812 RGBW at full white | ~1500 mA | |
| **Peak local load** | | **~1.51 A** |

MP1584EN is rated 3 A output — comfortable margin. Efficiency at 1.5 A load, 24 V input: ~85 % from the datasheet curves. Input current: `1.51 × 5 / 24 / 0.85 ≈ 0.37 A per tile at 24 V`.

For 8 tiles chained, worst case through tile 1's connectors: **~3 A at 24 V**, well within 2×-pin-parallel header capacity (~6 A for 0.1" headers).

## 4. RS-485 subsystem detail

```
MAX485 (U3) pinout (SOIC-8):
   1  RO   ── to CH32V003 USART1_RX (PD6)
   2  RE'  ── tied to pin 3 (half-duplex: DE and RE' always match)
   3  DE   ── from CH32V003 GPIO (PD4); HIGH = driving, LOW = receiving
   4  DI   ── from CH32V003 USART1_TX (PD5)
   5  GND
   6  A    ── to edge connector pins 3 and 6 (both edges)
   7  B    ── to edge connector pins 4 and 5 (both edges)
   8  VCC  ── 5 V

Protection and biasing (populated only on first/last tiles):
   TVS diode between A-B (SM712 or PESD1CAN, £0.15)
   120 Ω termination: resistor between A and B, placed on endpoint tiles only
   680 Ω fail-safe bias: A→V+ and B→GND, placed on master only
```

### Bus throughput budget at 1 Mbps

- 1 bit = 1 µs. UART framing: 10 bits/byte (start + 8 + stop) = 10 µs/byte.
- Per-tile packet: `SOF(1) + ADDR(1) + CMD(1) + LEN(1) + 75B payload + CRC(1) = 80 bytes = 800 µs`.
- 32 tiles × 800 µs = 25.6 ms per full frame + broadcast LATCH (~50 µs).
- **Supports ~38 fps for 32 tiles at 1 Mbps.** Bump to 2.5 Mbps (CH32V003 USART can do this) for ~96 fps.

## 5. MCU subsystem detail

CH32V003F4P6 pin assignments for v1 (TSSOP-20):

| Pin | Name | Function | Net |
|---:|---|---|---|
| 1 | PD4 | GPIO output | `RS485_DE` (driver enable, also tied to /RE) |
| 2 | PD5 | USART1_TX | `TX` → MAX485 DI |
| 3 | PD6 | USART1_RX | `RX` ← MAX485 RO |
| 4 | PD7/NRST | Reset | pulled up, test point |
| 5 | PA1 | GPIO output (TIM1 CH2 optional) | `LED_DATA` → SK6812 chain |
| 6 | PA2 | GPIO | Reserved (v2 NBR_N) |
| 7 | GND | Ground | GND |
| 8 | PC0 | GPIO | Reserved (v2 NBR_E) |
| 9 | PC1 | GPIO | Reserved (v2 NBR_S) |
| 10 | PC2 | GPIO | Reserved (v2 NBR_W) |
| 11 | PC3 | GPIO | (spare) |
| 12 | PC4 | GPIO | (spare) |
| 13 | PC5 | GPIO | (spare) |
| 14 | PC6 | GPIO | (spare) |
| 15 | PC7 | GPIO | (spare) |
| 16 | PD0 | GPIO / OSCI | (spare) |
| 17 | PD1 | SWIO | **PROGRAMMING — WCH-LinkE** (do not load) |
| 18 | PD2 | GPIO | (spare) |
| 19 | PD3 | GPIO | (spare) |
| 20 | VDD | 5 V | 5 V rail (with 100 nF + 10 µF decoupling) |

Programming header (3-pin JST-SH or test pads): 5 V, GND, SWIO (PD1). Flashed by WCH-LinkE before install; over-the-bus OTA is a v2 firmware task.

## 6. LED chain

SK6812 RGBW data line is fed from `PA1` (CH32V003) via a 330 Ω series resistor (reduces reflections on the first LED's data input). 25 LEDs in a 5×5 grid, wired in classic snake order (row 0 left-to-right, row 1 right-to-left, etc.).

Decoupling: 100 nF per LED is overkill but good practice — budget allows. Minimum: one 10 µF bulk cap + 100 nF every 5 LEDs.

Absolute max current with all LEDs full white: 25 × 60 mA = 1.5 A. Buck is sized for 2 A → 25 % margin. If the user-facing brightness cap is set to 80 %, continuous worst case drops to 1.2 A.

## 7. Master module

```
ESP32-C3 (e.g. XIAO ESP32-C3 dev board):
   3V3  ─── from onboard USB/LDO
   GND  ─── shared with 24 V PSU GND!!  ← critical
   GPIO0 ── UART0 TX ─► MAX485 DI
   GPIO1 ── UART0 RX ─◄ MAX485 RO
   GPIO2 ── GPIO ────► MAX485 DE (tied to /RE)

MAX485 (master side, SOIC-8):
   VCC   ─── 5 V (can derive from USB or step-up from 3.3 V; 3.3 V-tolerant variants exist — check datasheet)
   A     ─── to bus A, via 120 Ω termination to B
                            and 680 Ω bias to V+
   B     ─── to bus B, via 680 Ω bias to GND

Master 24 V → tile chain V+: wired directly (PSU feeds the chain, master logic
powered from USB — separate rail for clean operation during firmware work).
```

**Critical:** master GND and 24 V PSU GND must be **the same net**. If not, the RS-485 common-mode reference is undefined and you'll get intermittent bit errors.

## 8. Consolidated netlist (per tile)

For reference when laying out the PCB.

```
NET V24        J1.2, J1.7, J2.2, J2.7, F1.1, (no decoupling — pass-through)
NET V24_LOCAL  F1.2, Q1.source
NET V24_FUSED  Q1.drain, D1.+, C1.+, U1.2 (VIN), U1.8 (VIN)
NET SW         U1.7, L1.a, D2.cathode
NET V5         L1.b, D2.anode_NO (Schottky anode = GND side), C_OUT1+, C_OUT2+, U1.5 via feedback divider, U2.20 (VDD), U3.8 (VCC), LED[0].VCC..LED[24].VCC
NET GND        J1.1, J1.8, J2.1, J2.8, D1.-, C1.-, U1.6, D2.anode (SS34 cathode = SW, anode = GND), C_OUT*.-, R_FB_lo, U2.7 (GND), U3.5 (GND), LED[*].GND
NET BUS_A      J1.3, J1.6, J2.3, J2.6, U3.6 (A)
NET BUS_B      J1.4, J1.5, J2.4, J2.5, U3.7 (B)
NET UART_TX    U2.2 (PD5), U3.4 (DI)
NET UART_RX    U2.3 (PD6), U3.1 (RO)
NET RS485_DE   U2.1 (PD4), U3.2 (RE'), U3.3 (DE)
NET LED_DATA   U2.5 (PA1), R_SERIES, LED[0].DIN
```

(`LED[i]` is the i-th SK6812 in the chain; DOUT of each connects to DIN of the next.)

## Open electrical questions

- **Ground pour under buck switch node** — keep SW node area minimised; pour under VOUT only. Will be addressed in PCB layout.
- **ESD on edge connector pins** — TVS on bus already specced; V+ and GND pins see transients too. Consider TVS arrays on all four pins of the connector in the PCB version.
- **Brown-out on master when chain is live-connected** — inrush from C1 (47 µF × 32 tiles = 1.5 mF) at 24 V is severe. Add NTC inrush limiter at the PSU or soft-start resistor on the first tile's polyfuse branch.

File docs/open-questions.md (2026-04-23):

# Open Questions and Risks

Live list of things we don't yet know or haven't decided. Resolve and remove items as they close out. See also the closed/settled list at the bottom.

## Must resolve before PCB order

- [ ] **Edge connector physical form.** 1×8 pin header + socket (cheap, proven, one mating direction) vs spring pogo strips (lower profile, more mating cycles, needs tighter alignment) vs Amphenol/Molex mezzanine (rigid, expensive). Target: decide from 4-tile bench test data.
- [ ] **Mechanical alignment feature.** FDM printing tolerance on PETG is ±0.3 mm. Need dowel+pocket, keyed edges, or machined inserts.
- [ ] **Bus termination strategy.** Fixed at endpoints (simple, but endpoints must be known) vs switchable per-tile (complex, but any tile can be the endpoint). v1: fixed, master + designated "terminator" tile at far end.
- [ ] **Bus biasing.** RS-485 idle-state biasing (680 Ω to V+ on A, 680 Ω to GND on B). Populated on master only, or on first tile?

## Must resolve before firmware v1

- [ ] **Discovery timing.** Implement the 1-Wire-style binary-tree UID search on RS-485 and measure. Expected ~2 s for 32 tiles at 1 Mbps.
- [ ] **Frame synchronisation mechanism.** Proposed: master sends per-tile `SET_PIXELS`, then a broadcast `LATCH` command. Verify timing jitter across tiles under worst-case load.
- [ ] **Firmware update path.** Field-updatable tiles? Over the bus, or only via WCH-LinkE programmer? Bus-based firmware update is non-trivial with only 16 KB flash (bootloader budget).

## Must resolve before calling it done

- [ ] **Thermal.** 25 SK6812 at full white ≈ 7.5 W per tile. Diffuser standoff, vent pattern, and/or a global brightness cap in firmware.
- [ ] **EMI.** Differential RS-485 + 24 V linear power drop is low-risk, but buck switching noise needs measurement if CE/FCC is ever a goal.
- [ ] **License.** MIT / CERN-OHL-S / CC-BY-SA or something else.
- [ ] **v2 scope.** Commit to v2 (4-edge mesh, palindromic all round) only after v1 ships and we know real-world UX demand.

## Settled / resolved

- **Bus choice** → RS-485 multidrop, half-duplex, 1 Mbps. See [`architecture.md`](architecture.md). Parallel bus discarded.
- **Power distribution** → 24 V backbone, chained through connectors; per-tile buck converter to 5 V. See power math in architecture doc.
- **Edge connector pin count and layout** → 8 pins, palindromic: `GND, V+, A, B, B, A, V+, GND`. Identical pinout reserved on all 4 edges; v1 populates 2. Same connector supports v2 mesh without PCB respin.
- **Per-tile short isolation** → polyfuse on the local 24 V branch tap, leaving pass-through rail unaffected.
- **CH32V003 GPIO budget** → comfortable for v1 (UART TX/RX + DE, 1× LED output, 4× spare for v2 neighbour pins).
- **Topology for v1** → linear / serpentine chain. Map held at master, user arranges tiles in web UI. Free-form 2D mesh is v2.
- **Addressing** → UID-based auto-enumeration via 1-Wire-style binary search, adapted for RS-485. No hardcoded addresses.

## Claims from the original proposal that needed verification

- "Auto-addressing is a well-established pattern" — was unverified on a parallel bus. **Resolved** by switching to RS-485 with a 1-Wire-adapted search algorithm, which *is* well-established.
- ">60 fps for 100 tiles" — bandwidth math now in architecture doc: ~27 ms/frame for 32 tiles at 1 Mbps RS-485, comfortably >30 fps. 100 tiles at 1 Mbps is borderline; bump to 2–5 Mbps if needed. Verify on bench.
- "£2.62 per tile" — replaced with honest ~£8/tile figure driven by real parts and proper power regulation.
- "Keeps WLED ecosystem intact" — still partially true; a bridge that does 2D→tile slicing is needed. Not a blocker for v1 since we can ship a custom master UI first.

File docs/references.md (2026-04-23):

# References and Prior Art

## Closest reference project

- **[rmingon/led-wall](https://github.com/rmingon/led-wall)** — CH32V003F*P6 per tile, 8-bit parallel bus via 1×14 edge headers, SOF-based packet format with address byte and CRC8. Tile addresses are **hardcoded in `main.c`** — no auto-addressing in the reference. This is the closest existing implementation of the architecture sketched here.

## Related

- **[Modular LED Wall with CH32V006 RISC-V Slave Tiles](https://hackaday.io/project/203942-modular-led-wall-with-ch32v006-risc-v-slave-tiles)** — Similar approach on the larger CH32V006.
- **[CH32V003 Programming: How To Read 64-Bit Unique ID](https://pallavaggarwal.in/2023/09/25/ch32v003-programming-read-unique-id/)** — Reference for using the UID as tile identity.
- **[I2C automatic address assignment (Electronics Stack Exchange)](https://electronics.stackexchange.com/questions/85646/i2c-automatic-address-assignment)** — Auto-addressing pattern. Works cleanly on I2C because of open-drain arbitration; the parallel bus here would need a different mechanism.

## Upstream ecosystems we may borrow from

- **[WLED](https://github.com/Aircoookie/WLED)** — Established effects library and web UI. Could be used directly on the master, or forked, or used via DDP/E1.31 to a bus-driver bridge.
- **[E1.31 / sACN](https://www.esta.org/tsp/documents/published_docs.php)** and **[DDP](http://www.3waylabs.com/ddp/)** — Pixel delivery protocols over IP.

## OpenSCAD libraries available in `thirdparty/`

See [`thirdparty/README.md`](../thirdparty/README.md) for what's vendored as submodules and why each one is useful for this project.

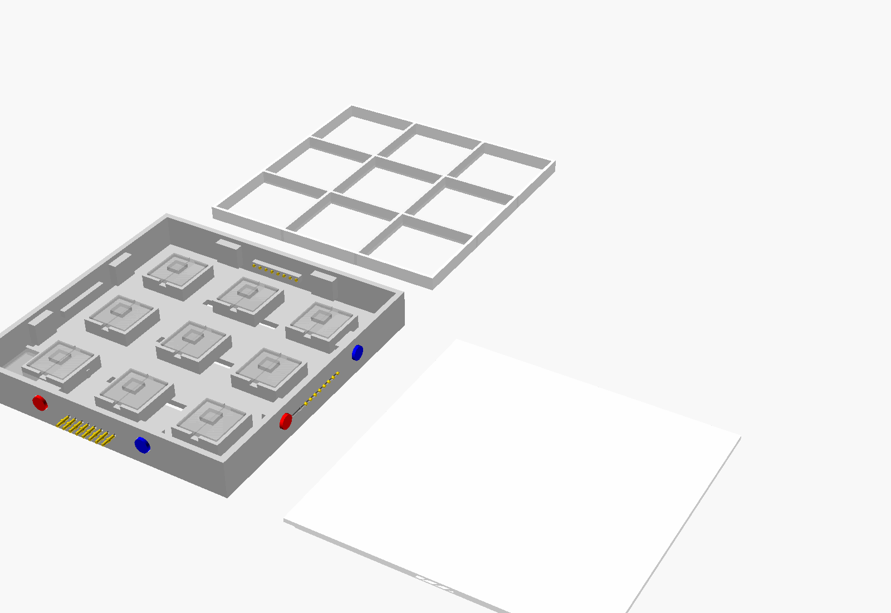
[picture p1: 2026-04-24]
mechanical/openscad/tile-preview.png

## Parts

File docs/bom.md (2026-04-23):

# Bill of Materials

Prices in GBP, estimated from LCSC / Mouser volume pricing (qty 100+) unless marked otherwise. Final BOM will be revised once real quotes and the 4-tile bench test land. For specific part numbers and hand-solder bench kit, see [`../prototypes/4-tile-bench/parts-list.md`](../prototypes/4-tile-bench/parts-list.md).

## Per tile (v1 — RS-485 + 24 V backbone)

| Component | Qty | Est. unit | Est. total | Notes |
|---|---:|---:|---:|---|
| SK6812 RGBW LED | 9 | £0.17 | £1.53 | 3 × 3 grid at 30 mm pitch — brightness, not display |
| CH32V003F4P6 MCU (TSSOP-20) | 1 | £0.12 | £0.12 | LCSC C5143676 |
| MAX485 / SP485EEN RS-485 transceiver | 1 | £0.35 | £0.35 | SOIC-8, 5 V |
| MP1584EN buck (24→5 V, 2 A) | 1 | £0.45 | £0.45 | TSOT-23-8 + L + Cs |
| Buck inductor + output caps + Schottky | — | — | £0.18 | 22 µH shielded, 2× 22 µF |
| P-MOSFET (reverse-polarity) | 1 | £0.10 | £0.10 | AO3401 or similar |
| TVS diode (SMBJ28CA, bidir) | 1 | £0.10 | £0.10 | 24 V rail clamp |
| Polyfuse (0.5 A hold) | 1 | £0.05 | £0.05 | Local branch protect |
| Bulk cap on 24 V tap | 1 | £0.08 | £0.08 | 47 µF, 35 V electrolytic |
| Edge connectors (2 × 8-pin header + socket, palindromic) | 1 set | £1.00 | £1.00 | Same pinout on all 4 edges reserved for v2; v1 populates 2 |
| PCB (100 × 100 mm, 4-layer) | 1 | £0.40 | £0.40 | JLCPCB volume |
| Passives (decoupling, pullups, term resistors) | ~15 | — | £0.15 | |
| Neodymium magnets 5 × 2 mm | 4 | £0.10 | £0.40 | Mating assist |
| PETG enclosure + alignment dowels | — | — | £0.30 | 3D printed |
| Diffuser sheet | 1 | — | £0.10 | |
| **Per-tile subtotal** | | | **~£5.31** | Down from £8.03 after cutting LED count from 25 to 9 |

## Per system (32-tile target)

| Line item | Qty | Est. cost | Notes |
|---|---:|---:|---|
| Tiles | 32 | £170 | 32 × £5.31 |
| ESP32-C3 master module | 1 | £5 | XIAO ESP32-C3 or equivalent |
| Master-side MAX485 + biasing + termination | 1 | £2 | |
| 24 V PSU | 1 | £15 | Mean Well LRS-100-24 (≈4 A) — 32 tiles × 2.7 W / 0.85 η / 24 V ≈ 4.3 A peak |
| Power distribution cable + connectors | 1 | £10 | 2 × 18 AWG sufficient for ~5 A + DC barrel/terminal |
| Array frame + back panel | 1 | £25 | Aluminium extrusion or plywood |
| Miscellaneous (fasteners, cable ties, strain relief) | — | £10 | |
| **System subtotal** | | **~£237** | Down from £344 — LED count reduction drops PSU size too |

## Cost comparison vs. the original sketch

| Version | Claimed | Reality |
|---|---:|---:|
| Original parallel-bus proposal | £107 | Understated; pogo pin pricing unrealistic, power distribution unaccounted for |
| v1 RS-485 + 24 V (this) | — | **~£337 all-in** for a working 32-tile system |

The system cost roughly triples compared to the original guess, because the original omitted power distribution, PSU, frame, and realistic connector pricing. £337 is still a reasonable price for a 32-tile custom LED wall.

## What still needs real quotes before PCB order

- SK6812 RGBW from a verified supplier (price varies 2× between reels)
- Edge connector choice (see [`open-questions.md`](open-questions.md))
- PCB quote once design is finalised
- Enclosure cost once mechanical design is drawn

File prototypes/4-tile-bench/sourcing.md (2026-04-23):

# Sourcing the bench kit

Guide to buying the bench kit. AliExpress is the cheapest path for most items. UK/EU reputable distributors (RS, Farnell/CPC, Mouser, Pimoroni, Digikey, Olimex) are faster and more reliable but 2–4× more expensive — used here mainly for the counterfeit-risk parts.

The links below were verified at commit time. **AliExpress URLs rot fast** — if a specific listing 404s, the search strings in [§ search strings and seller archetypes](#search-strings-and-seller-archetypes) will find equivalents. Paired with [`parts-list.md`](parts-list.md) for quantities.

## Quick-start verified listings

Headline purchases for the bench kit, with both cheapest (AliExpress / LCSC) and UK/EU-reputable sources.

| Part | Cheapest (China) | UK/EU reputable | Notes |
|---|---|---|---|
| **CH32V003F4P6** (MCU, TSSOP-20) | [LCSC C5187096](https://www.lcsc.com/product-detail/C5187096.html) (~$0.12 @ qty 100), or [AliExpress 100pcs](https://www.aliexpress.com/item/1005006178321495.html) | **Not stocked at RS/Farnell/CPC/Mouser UK** — WCH chips are LCSC/AliExpress distribution only | Order from LCSC if you want fewer clone concerns; AliExpress for small qty |
| **WCH-LinkE** programmer | [AliExpress listing](https://www.aliexpress.com/item/1005007777129888.html) (~£4–5); also [LCSC kit with eval board + programmer](https://www.lcsc.com/product-detail/Microcontroller-Units-MCUs-MPUs-SOCs_WCH-Jiangsu-Qin-Heng-CH32V003F4P6-EVT-WCH-LinkE_C5236707.html) | [Olimex WCH-LinkE (EU)](https://www.olimex.com/Products/RISC-V/WCH/WCH-LinkE/) (~€8) | Olimex is authentic and EU-shipped; AliExpress is usually fine for this simple programmer |
| **MAX485ESA+** RS-485 transceiver | [AliExpress MP1584 + MAX485 combo kits](https://www.aliexpress.com/item/32261885063.html) — use search strings below for MAX485-only | [CPC Farnell MAX485CSA+ SC19150](https://cpc.farnell.com/maxim-integrated-analog-devices/max485csa/bus-transceiver-smd-soic8-485/dp/SC19150) (~£1.40/ea), Mouser UK, RS Components | **Buy this one from a reputable UK source.** MAX485 is heavily cloned on AliExpress and clones fail at 1 Mbps. Few £ savings not worth the debugging time. |
| **MP1584EN buck module** | [AliExpress 1pc listing](https://www.aliexpress.com/item/32261885063.html), [AliExpress module listing](https://www.aliexpress.com/item/32828603866.html) (buy in 10-packs) | [Opencircuit MP1584EN module (EU)](https://opencircuit.shop/product/mp1584en-mini-buck-converter-4.5v-28v-module), Pimoroni carries similar | AliExpress 10-pack is fine — these modules are hard to fake meaningfully |
| **SK6812 RGBW 5050 natural white, 100 pcs** | [AliExpress 100/1000pcs RGBW listing](https://www.aliexpress.com/item/Germany-warehouse-100pcs-1000pcs-SK6812-IC-Bulit-in-5050-RGB-RGBW-RGBW-CCT-SMD-Addressable-LED/32580793956.html), [BTF-LIGHTING on AliExpress](https://www.aliexpress.us/item/2251832628463811.html) | [BTF-LIGHTING SK6812 100pcs RGBW Natural White on Amazon](https://www.amazon.com/BTF-LIGHTING-Natural-5050SMD-WS2812B-Addressable/dp/B0DNJJNBHJ) | BTF-LIGHTING is the well-regarded brand; buy direct from them on AliExpress or via Amazon for faster UK delivery |
| **XIAO ESP32-C3** (master) | ~£3 clones on AliExpress (search `XIAO ESP32C3`) | [Pimoroni UK](https://shop.pimoroni.com/en-us/products/seeed-studio-xiao-esp32c3) (~£6–7), [Mouser Europe 113991054](https://eu.mouser.com/ProductDetail/Seeed-Studio/113991054?qs=3Rah4i+hyCHVBerMrpzCkw%3D%3D), [Digikey 113991054](https://www.digikey.com/en/products/detail/seeed-technology-co-ltd/113991054/16652880) ($4.99) | Pimoroni ships UK next day; genuine Seeed board |

## Key finding: CH32V003 is effectively China-only distribution

Confirmed at commit time: **RS Components UK, Farnell UK, CPC UK, and Mouser UK do not stock the CH32V003 in any variant.** WCH (the manufacturer) distributes via LCSC, AliExpress, and a small number of regional distributors. Practical implication:

- Order CH32V003 chips from **LCSC** (lcsc.com) — shipping is ~£15 from Shenzhen to UK via DHL / FedEx (7–10 days), or ~£5 via standard post (2–3 weeks). Minimum order thresholds are low.
- **Do not wait for RS/Farnell to stock it** — they don't, and probably won't in the short term.
- For the first prototype, 10 units cost ~£1.50 on LCSC + shipping. Bundle with other parts to amortise shipping.

## Search strings and seller archetypes

Once the verified links above rot, use these search patterns to find equivalents.

### Shipping tiers (matters for timing)

- **AliExpress Standard Shipping** — tracked, typically 15–25 days to UK. Best default for non-urgent bulk buys.
- **AliExpress Choice** / **Cainiao Premium** — often 10–15 days, sometimes free over a threshold.
- **EU Shipping** / **Local warehouse** — 3–7 days, more expensive, stock limited to popular items.
- **Standard free** (no tracking) — do not use for anything over £5.

Order everything in one or two baskets with the same shipping tier so parts arrive together.

## Reputable seller archetypes

AliExpress sellers come and go, but these *types* of sellers reliably sell the real thing:

- **"WCH Official Store"** — authentic CH32V003 and WCH-LinkE programmers. Search `WCH official` on AliExpress.
- **"LCSC" on AliExpress is NOT the same as lcsc.com** — beware. Use lcsc.com directly for LCSC pricing; the AliExpress lookalikes are unrelated.
- **"Chip CBM"**, **"Utsource"**, **"IC Brand"** — typically authentic branded silicon (MAX485, MP1584) but check reviews for counterfeits.
- **"BTF-LIGHTING"**, **"AKwil"**, **"Chinly"** — established SK6812 / WS2812 suppliers with consistent quality.
- **"Makerbase"**, **"HiLetgo"**, **"DIYmore"** — reliable for dev boards and modules.

**Always check:** seller age > 1 year, seller rating > 96 %, listing has > 100 orders, at least a few text reviews (not just photo reviews).

## Counterfeit-risk parts

These commonly get cloned on AliExpress. Either buy from Mouser/Digikey/LCSC instead, or be prepared to reject a batch:

| Part | Counterfeit risk | How to mitigate |
|---|---|---|
| MAX485 | **High** — clones use NE5090 or unmarked silicon, work at 100 kbps but fail at 1 Mbps | Buy SP485EEN or MAX485ESA from LCSC/Mouser, or accept ~25 % reject rate from AliExpress |
| FT232RL | **Very high** — old FTDI driver versions refused to work with clones | Buy CH340-based adapters instead (not commonly cloned) |
| SK6812 RGBW | **Medium** — often mixed with WS2812B or de-rated LEDs | Stick to BTF-Lighting / Chinly branded reels |
| CH32V003 | **Low** — too cheap to be worth cloning; but verify the IC marking reads "CH32V003" | Buy from WCH official or high-reputation sellers |
| MP1584EN | Low (module), medium (bare IC) | Buy pre-built modules for bench — clones are rare and usually still work |

Rule of thumb: **anything priced < 50 % of the Mouser price and < 80 % of LCSC price is suspect.**

## The shopping list

Grouped for bundling into single orders. Prices are typical AliExpress (qty-10 where applicable, inclusive of standard shipping) as of late 2025 / early 2026 — confirm before buying.

### Order 1 — MCUs, transceivers, protection ICs

Search on AliExpress, sort by orders, filter to 4-star+ sellers.

| Part | Search string | Qty | Expected total £ | Notes |
|---|---|---:|---:|---|
| CH32V003F4P6 | `CH32V003F4P6 TSSOP-20` | 10 | 1.50–3.00 | Sold in lots of 5 or 10. Often cheaper in 10-lots. |
| WCH-LinkE programmer | `WCH-LinkE` or `CH32V WCH-Link` | 1 | 3–5 | Needed to flash CH32V003. One is enough. |
| MAX485 SOIC-8 | `MAX485 SOIC-8` or `MAX485ESA` | 10 | 3.00–6.00 | If cheap (< £0.30/ea), expect some clones. |
| SP485EEN (alternative) | `SP485EE SOIC-8` | 10 | 5.00–8.00 | Lower clone rate than MAX485. |
| AO3401 P-MOSFET | `AO3401 SOT-23` | 50-pack | 1.00–2.00 | Buy in 50-packs, use elsewhere. |
| SMBJ28CA TVS | `SMBJ28CA` | 20-pack | 1.00–2.00 | Bidirectional variant (`CA` suffix). |
| SS34 Schottky | `SS34 SMA` | 50-pack | 1.00–2.00 | Standard buck freewheel. |
| **Order 1 subtotal** | | | **~£12–28** | |

### Order 2 — MP1584 modules (bench-speed shortcut)

For the bench prototype, **do not** populate MP1584 IC + inductor + caps discretely — it just adds debugging time. Buy ready-made modules and screw-set them to 5.00 V.

| Part | Search string | Qty | Expected total £ | Notes |
|---|---|---:|---:|---|
| MP1584EN buck module (adjustable, 3 A) | `MP1584EN 3A buck module adjustable` | 10 | 6–10 | Pre-assembled, pin headers, trim pot. |
| **Order 2 subtotal** | | | **~£6–10** | |

When the PCB lands, the discrete MP1584 components belong in order 1 instead. For bench, modules win.

### Order 3 — LEDs

| Part | Search string | Qty | Expected total £ | Notes |
|---|---|---:|---:|---|
| SK6812 RGBW individual chips (5050 package) | `SK6812 RGBW 5050 LED 100pcs` | 200–300 | 20–30 | Buy enough for 10 tiles (250) plus spares. |
| **— alternative —** SK6812 strip at 60 LED/m | `SK6812 RGBW 60LED natural white 5m` | 5 m | 25–35 | If you want to desolder from strip (fiddly) — *not recommended*. |
| **Order 3 subtotal** | | | **~£20–30** | |

Ask seller for **natural white (4000K)** variant unless you specifically want warm or cool. Confirm it says "SK6812 RGBW" — some sellers substitute WS2812B RGB at the last minute.

### Order 4 — Passives

Buy passives in **assortment kits** — it's cheaper than individual values and you'll need the spares.

| Part | Search string | Qty | Expected total £ | Notes |
|---|---|---:|---:|---|
| 0603 resistor assortment (e.g. 170 values × 25 each) | `0603 SMD resistor assortment kit` | 1 kit | 8–15 | Covers everything below 1 W. |
| 0603 ceramic cap assortment (inc. 100 nF, 22 µF, 10 µF) | `0603 SMD capacitor sample book` | 1 kit | 8–15 | 10k+ caps, useful for years. |
| Electrolytic 47 µF/35 V | `47uF 35V electrolytic radial` | 20-pack | 1.50 | For C1 tile input bulk. |
| Polyfuse 0.5 A / 1 A 1812 SMD | `polyfuse 1812 0.5A SMD` | 20-pack | 2.00 | |
| 22 µH shielded inductor, 3 A sat | `22uH 3A shielded inductor SMD` | 20-pack | 4.00 | Only needed if going discrete on the buck (skip if using modules). |
| 120 Ω precision resistors 1 % | Part of 0603 kit | — | — | Check the kit includes 120 Ω and 680 Ω; if not, buy separately. |
| **Order 4 subtotal** | | | **~£20–35** | |

### Order 5 — Connectors and mechanical

| Part | Search string | Qty | Expected total £ | Notes |
|---|---|---:|---:|---|
| 2.54 mm 1×8 male pin header (straight) | `2.54mm 1x8 pin header straight 20pcs` | 30 | 2.00 | Cheap; cut from 40-pin strips if needed. |
| 2.54 mm 1×8 female socket | `2.54mm 1x8 female pin socket 20pcs` | 30 | 3.00 | |
| Dupont jumper wires M-M, M-F, F-F (40 of each) | `Dupont jumper wire 40pcs` | 1 set | 3–5 | Essential for bench prototyping. |
| Perfboard 50×70 mm | `prototype PCB 50x70 double sided 10pcs` | 10 | 4–6 | One per tile + spares. |
| Screw terminals 2-pos 5.08 mm | `screw terminal 5.08mm 2 pin` | 10 | 2.00 | For 24 V input on master. |
| Neodymium magnets 5 × 2 mm | `neodymium magnet 5x2mm 50pcs` | 50 | 3–5 | Tile edge mating assist. |
| **Order 5 subtotal** | | | **~£17–23** | |

### Order 6 — Test gear and master

| Part | Search string | Qty | Expected total £ | Notes |
|---|---|---:|---:|---|
| 24 V / 2 A desktop PSU (barrel plug) | `24V 2A power supply 5.5x2.1mm` | 1 | 8–12 | Adequate for 4-tile bench; bigger LRS-350 needed for 32-tile system. |
| XIAO ESP32-C3 dev board | `XIAO ESP32-C3` or `Seeed XIAO ESP32-C3 clone` | 1 | 4–7 | Genuine Seeed or clone; clones are usually fine. |
| USB-RS485 adapter (CH340 + SP485) | `USB to RS485 CH340 SP3485` | 1 | 3–6 | For bus sniffing from a laptop. CH340-based preferred over FT232 clones. |
| Small logic analyser (8 ch, 24 MHz) if not owned | `Saleae 8 channel logic analyzer clone USB` | 1 | 5–10 | Pairs with sigrok/PulseView free software. |
| **Order 6 subtotal** | | | **~£20–35** | |

## Grand total

| Order | £ |
|---|---:|
| 1 — ICs | ~12–28 |
| 2 — MP1584 modules | ~6–10 |
| 3 — LEDs | ~20–30 |
| 4 — Passives | ~20–35 |
| 5 — Connectors / mech | ~17–23 |
| 6 — Test gear and master | ~20–35 |
| **Total AliExpress** | **~£95–160** |

Typical landed cost: **~£120** for everything needed to build and bring up 4 tiles on the bench, with spares for 8.

If you already own a bench PSU, WCH-LinkE, logic analyser, and USB-RS485 adapter, the actual consumable parts are **~£60–90**.

## What NOT to buy on AliExpress

- **Authentic branded RS-485 transceivers** if you need 1 Mbps reliability with zero clone roulette — get from Mouser/Digikey/LCSC proper.
- **FTDI chips** — the clone saga is still not fully over; use CH340 alternatives.
- **PCBs for the final product** — JLCPCB (not on AliExpress) is cheaper and better.
- **Precision 1 % resistors** if you need the 1 % — assortment kits are nominally 1 % but often 5 %. For the buck feedback divider, measure with a DMM before placing.

## Before placing the order

- [ ] Verify the seller accepts PayPal (easier dispute resolution if items don't arrive).
- [ ] Read the last 20 reviews — look for "item not as described" or "sent wrong chip".
- [ ] Check the listing photos carefully — many sellers show a photo of the genuine chip but ship unmarked clones.
- [ ] Check shipping tier — "Choice" is a trap if the threshold isn't met.
- [ ] Combine orders from the same seller to save on shipping.
- [ ] Take screenshots of listings (in case the seller relists with different terms mid-dispute).

## When parts arrive

- [ ] **Verify IC markings with a loupe** — "MAX485" clones often have slightly wrong font or spacing.
- [ ] Measure a buck module at a known load before soldering — 5 V trim pot can be mis-adjusted from factory.
- [ ] Test **one SK6812** from the reel with a known-good controller (Arduino + FastLED) before committing 25 to a tile.
- [ ] Check the CH32V003 is flashable — connect WCH-LinkE and read UID. Non-programmable units (rare but possible) save debugging time later.

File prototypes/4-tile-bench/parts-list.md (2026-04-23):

# Parts list — 4-tile bench kit (buy for 8)

Quantities sized for 8 assemblies so there's slack for damage, dead-on-arrival units, and one-step scale-up. Prices are sanity-check estimates (qty 10–100, LCSC/Mouser/AliExpress); confirm on the supplier site before ordering. Total target: **~£135** for the bench kit including a small PSU.

## Semiconductors

| Designator | Part | Qty | Supplier ref | Est. £ each | Total | Notes |
|---|---|---:|---|---:|---:|---|
| U2 | CH32V003F4P6 (TSSOP-20) | 10 | LCSC C5143676 | 0.15 | 1.50 | MCU |
| U3 | MAX485ESA+ (SOIC-8) | 10 | Mouser 700-MAX485ESA | 0.60 | 6.00 | RS-485 transceiver (5 V). SP485EE or MAX3485 (3.3 V) are alternates |
| U1 | MP1584EN (TSOT23-8) | 10 | LCSC C6712 | 0.50 | 5.00 | Or **buy ready-made MP1584 modules** for bench (see below) |
| Q1 | AO3401 P-MOSFET (SOT-23) | 10 | LCSC C15127 | 0.08 | 0.80 | Reverse-polarity protection |
| D1 | SMBJ28CA TVS (SMB) | 10 | LCSC C24327 | 0.12 | 1.20 | 24 V rail clamp, bidir |
| D2 | SS34 Schottky (SMA) | 10 | LCSC C8598 | 0.10 | 1.00 | Buck freewheel |
| — | **SK6812 RGBW 5050** | 250 | LCSC C965556 or AliExpress | 0.15 | 37.50 | 25 per tile × 10 for slack |

**Bench shortcut:** instead of discrete MP1584 circuits, buy **MP1584EN step-down modules** (AliExpress / Amazon, £1–2 each in 5-packs) pre-populated with inductor, caps, and a trim pot. Adjust trim pot to 5.00 V once, solder in. Eliminates most of the buck debugging and gets you to first-light faster. We'll do the discrete implementation on the PCB.

## Passives

| Designator | Value | Pkg | Qty (for 8 tiles) | Est. £ | Notes |
|---|---|---|---:|---:|---|
| F1 | Polyfuse 0.5 A hold / 1 A trip | 1812 SMD | 10 | 0.40 | Littelfuse 1812L050 or similar |
| C1 | 47 µF / 35 V electrolytic | through-hole radial | 10 | 0.50 | Input bulk |
| C_OUT1, C_OUT2 | 22 µF / 10 V X7R | 1206 | 20 | 1.00 | Buck output bulk |
| C_BYP (scattered) | 100 nF / 25 V X7R | 0603 | 50 | 0.50 | Decoupling everywhere |
| C_LED_BULK | 10 µF / 10 V X7R | 1206 | 10 | 0.30 | LED strip bulk, 1 per tile |
| L1 | 22 µH shielded, 3 A sat | SMD or through-hole | 10 | 2.50 | For MP1584 discrete (skip if using modules) |
| R_FB_HI | 10 kΩ 1 % | 0603 | 10 | 0.05 | Feedback divider high side |
| R_FB_LO | 3.16 kΩ 1 % | 0603 | 10 | 0.05 | Feedback divider low side → 5.00 V |
| R_COMP | 22 kΩ | 0603 | 10 | 0.05 | Buck loop comp |
| C_COMP | 2.2 nF | 0603 | 10 | 0.05 | Buck loop comp |
| R_LED_SERIES | 330 Ω | 0603 | 10 | 0.05 | On LED data line |
| R_MCU_PU | 10 kΩ | 0603 | 30 | 0.10 | NRST pullup, DE pulldown, etc. |
| R_TERM | 120 Ω 1 % | 0603 | 5 | 0.05 | Bus termination (2 needed + spares) |
| R_BIAS | 680 Ω | 0603 | 5 | 0.05 | Bus biasing at master (2 needed) |

## Connectors and mechanical

| Item | Qty | Est. £ | Notes |
|---|---:|---:|---|
| 1×8 male pin header (2.54 mm) | 20 | 1.50 | 2 per tile + master + spares |
| 1×8 female socket (2.54 mm) | 20 | 2.00 | Female side used depending on chain orientation |
| 3-pin 2.54 mm header (programming) | 10 | 0.50 | SWIO + 5 V + GND |
| Phoenix / screw terminal 2-pos | 2 | 1.00 | 24 V PSU input at master |
| Perfboard / stripboard 50 × 70 mm | 10 | 5.00 | One per tile |
| Hook-up wire assortment | — | 5.00 | 22 AWG |
| Solid-core jumper wire | — | 3.00 | For protoboard bridging |

## Tools and instruments

| Item | Qty | Est. £ | Notes |
|---|---:|---:|---|
| WCH-LinkE programmer | 1 | 4.00 | Flashes CH32V003 |
| USB-RS485 adapter (FT232RL or CH340 + MAX485) | 1 | 8.00 | For master-side testing and bus sniffing |
| 24 V / 2 A bench PSU | 1 | 30–60 | Mean Well LRS-50-24 is ~£15 if you already have an enclosure/fuse; add 5 V USB for logic separately |
| XIAO ESP32-C3 dev board | 1 | 5.00 | Master MCU |
| USB-to-USB-C cable | 1 | 3.00 | For ESP32-C3 |

**Already-owned assumptions:** logic analyser (e.g. Saleae / cheap 8-ch clone), DMM, soldering iron, oscilloscope with ≥50 MHz BW (helpful for eye diagrams on RS-485).

## Total estimate

| Category | £ |
|---|---:|
| Semiconductors | ~52 |
| Passives | ~6 |
| Connectors and mechanical | ~18 |
| Tools and instruments | ~50–80 |
| **Total (with PSU and programmer)** | **~£125–155** |

If WCH-LinkE and USB-RS485 adapter are already owned, drops to ~£85–115.

## Sourcing notes

- **LCSC** is cheapest for CH32V003, MP1584, most passives — factor in postage (~£15 from CN to UK, 2–3 weeks) or use JLCPCB's parts service.
- **Mouser / Digikey** for authentic MAX485 if you've been burned by counterfeits (MAX485 is heavily cloned).
- **AliExpress** for MP1584 ready-made modules, SK6812 reels, and pogo-pin test accessories.
- **For UK same-day needs** (breakage, replacements): Pimoroni, The Pi Hut, CPC Farnell — roughly 2× LCSC pricing but available tomorrow.

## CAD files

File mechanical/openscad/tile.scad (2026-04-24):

// openluminance — tile mechanical assembly, draft v0.3
//
// TWO-PIECE print: FRAME (main body, closed back, open front) + DIFFUSER
// (100 × 100 × 1.5 mm panel with a continuous inner rim that press-fits
// into the frame opening). The back cap of earlier drafts is merged into
// the frame as an integrated rear wall with ventilation slots.
//
// The diffuser covers the entire front face edge-to-edge, so when two
// tiles sit side-by-side the glow runs continuously across the seam —
// no visible frame lip interrupting the line.
//
// Overall assembled height: 15 mm (frame 13.5 mm + diffuser 1.5 mm).
//
// EDGE CONNECTOR — matches the 8-pin palindromic spec in
// docs/architecture.md. Reading pins 1..8 at increasing Y along the +X
// edge:
//
//     pin 1 (low Y)  → GND
//     pin 2          → V+   (24 V backbone)
//     pin 3          → BUS_A
//     pin 4          → BUS_B
//     pin 5          → BUS_B  (paralleled with pin 4)
//     pin 6          → BUS_A  (paralleled with pin 3)
//     pin 7          → V+     (paralleled with pin 2)
//     pin 8 (high Y) → GND    (paralleled with pin 1)
//
// 24 V POWER RAIL — not a separate bus bar. It's distributed by the PCB:
// V+ pins on every populated edge tie to a single V+ net; GND pins all
// tie to a single GND net. Power enters on any edge, exits on any
// (unoccupied) neighbouring edge. The buck converter on the PCB taps
// this net locally. With all 4 edges populated, power can flow in any
// direction through the tile array — no dedicated power-injection edge
// required.
//
// BUS_A and BUS_B behave similarly for the RS-485 signal, with one
// wrinkle: a full 4-edge tie would make the bus a mesh with reflections.
// The v1 PCB populates BUS_A/BUS_B on only two edges (one chain). v2
// PCBs will use per-edge analogue switches (e.g. TS5A3166) to make the
// bus routable under firmware control. The frame geometry is the same
// for both.
//
// EDGE MAGNETS — tiles attach edge-to-edge. Two magnets per populated
// edge, offset from the edge midpoint. Polarity follows a CCW-handed
// rule so any edge pair mates correctly in any rotation:
//
//     +X edge    N outward at LOW Y,   S outward at HIGH Y
//     +Y edge    N outward at HIGH X,  S outward at LOW X
//     -X edge    N outward at HIGH Y,  S outward at LOW Y
//     -Y edge    N outward at LOW X,   S outward at HIGH X
//
// COORDINATE SYSTEM — the SCAD model uses "use orientation":
//     z = 0           → closed back outer face (build plate when printing)
//     z = BACK_THICK  → back inner face (interior begins)
//     z = FRAME_H     → top of the frame walls (where the diffuser sits)
//     z = TILE_HEIGHT → diffuser front face (assembled tile outer front)
//
// PRINT ORIENTATION — frame prints back-face DOWN on the build plate, no
// overhangs except the back-face vent slots (bridges cleanly). Diffuser
// prints flat, rim up or down either way.
//
// Set RENDER at the top to export a specific part.

/* ============================ parameters ============================ */

RENDER           = "assembly";   // "frame" | "diffuser" | "light_guide" | "assembly"

// ----- overall -----
TILE_SIZE        = 100;
TILE_HEIGHT      = 15;

// ----- split: frame height + diffuser thickness = TILE_HEIGHT -----
DIFFUSER_THICK   = 1.5;
FRAME_H          = TILE_HEIGHT - DIFFUSER_THICK;   // 13.5

// ----- frame walls and back -----
WALL_THICK       = 2;
BACK_THICK       = 2;     // integrated rear wall (was the "back cap")

// ----- interior Z anchors -----
// No central PCB in this design — the controller is a pre-made dev board
// (XIAO ESP32-C3, CH32V003 breakout, or similar) dropped into a pocket
// in one corner, and the LEDs are individual pre-made SK6812 modules
// seated in cradles on a 3 × 3 grid. The Z anchors below are kept for
// the connector and magnet geometry; they describe the plane where the
// LED module top face ends up (= where a flat PCB top would have been).
LED_MOD_PCB_TH   = 1.6;   // LED module PCB thickness (typical)
LED_MOD_STACKUP  = 4.0;   // height from back inner face to bottom of LED module
LED_MOD_BOT_Z    = BACK_THICK + LED_MOD_STACKUP;       // 6.0 — cradle top
LED_MOD_TOP_Z    = LED_MOD_BOT_Z + LED_MOD_PCB_TH;     // 7.6
LED_HEIGHT       = 1.5;                                // SK6812 body above module PCB
LED_TOP_Z        = LED_MOD_TOP_Z + LED_HEIGHT;         // 9.1
DIFFUSER_GAP     = FRAME_H - LED_TOP_Z;                // 4.4

// ----- LED module cradles -----
// Each cradle is a raised pad at the LED module's X/Y position, with a
// small retention lip around the module footprint. Module drops in and
// is held by friction + lip; no glue, no screws. Wires exit via a slot
// on one side of each cradle.
LED_MOD_XY       = 15;     // module footprint (typical pre-made SK6812 single-LED breakouts)
CRADLE_XY        = LED_MOD_XY + 2.4;   // outer — module + 1.2 mm lip per side
CRADLE_LIP_T     = 1.0;    // lip height above module top surface
CRADLE_Z_LO      = BACK_THICK;         // cradle base = back inner face
CRADLE_Z_HI      = LED_MOD_BOT_Z;      // cradle top — module rests here
CRADLE_WIRE_SLOT_W = 3.0;              // slot on -Y side of each cradle for wires

// ----- MCU board pocket -----
// Flat area in the -X,-Y corner where a pre-made MCU board (e.g. a
// XIAO ESP32-C3 at 21 × 17.5 mm, or a CH32V003 breakout ~ 20 × 15 mm)
// drops in. No screws by default — retained by a pair of clip ribs on
// the long sides. Wires run from the board to the LED chain and to
// each edge connector.
MCU_POCKET_X     = 26;     // floor width (room for boards up to 24 mm)
MCU_POCKET_Y     = 20;     // floor depth
MCU_POCKET_ORIG  = [3, 3]; // inset from the tile -X,-Y corner
MCU_RIB_T        = 1.2;    // retention rib thickness (one per long side)
MCU_RIB_H        = 3.0;    // rib height above back inner face

// ----- edge connector -----
CONN_TYPE        = "pogo";   // "pogo" | "header"
CONN_PINS        = 8;
CONN_PITCH       = 2.54;
// Populate ALL FOUR edges by default. The frame supplies the geometry;
// the PCB decides which edges' signal pins are tied together (see
// header comment on 24 V power rail). Set to [0, 2] to model a v1
// PCB that only routes a linear chain.
CONN_EDGES       = [0, 1, 2, 3];   // 0=+X, 1=+Y, 2=-X, 3=-Y

// SHORT double-ended pogo pin — just enough to protrude and make contact
// when tiles sit essentially wall-to-wall. Common "short spring contact"
// or "short pogo pin" format on LCSC / AliExpress — search for e.g.
// "1.0mm pogo pin 5mm" or "P50-B short spring contact".
//
//   free length        5.0 mm (tip-to-tip, uncompressed)
//   compressed        ~4.0 mm
//   wall exposure      0.5 mm at each tile's outer face (at rest)
//   compressed gap     2 × 0.5 = 1 mm compression when mated (0.5 per side)
//   wall-to-wall gap  ~0 mm — tiles sit flush, springs loaded
POGO_PIN_OD      = 1.0;
POGO_PIN_HOLE    = 1.1;
POGO_FLANGE_OD   = 1.5;
POGO_FLANGE_H    = 0.6;
POGO_FREE_LEN    = 5.0;
POGO_COMPRESSED  = 4.0;
POGO_WALL_EXPOSE = 0.5;

// 1×8 pin header fallback
HEADER_BODY_W    = CONN_PINS * CONN_PITCH + 0.8;
HEADER_BODY_H    = 2.5;
HEADER_SLOT_H    = HEADER_BODY_H + 1.0;

// connector z-center: where edge breakout boards will sit (formerly
// coincided with the PCB mid-plane; same Z in this design)
CONN_Z_CENTER    = (LED_MOD_BOT_Z + LED_MOD_TOP_Z) / 2;   // 6.8

// ----- magnets (neodymium 5 × 2 mm discs) -----
MAG_OD           = 5;
MAG_H            = 2;
MAG_CLEAR_RAD    = 0.15;
MAG_CLEAR_AX     = 0.2;

EDGE_MAGNETS     = true;
BACK_MAGNETS     = false;   // only needed for metal-backplate wall mount
EDGE_MAG_OFFSET  = 20;      // from edge midpoint along the edge
EDGE_MAG_BOSS_D  = 3;       // inward extension from inner wall face
EDGE_MAG_BOSS_W  = 9;       // width along edge (> MAG_OD)
EDGE_MAG_BOSS_H  = 8;       // Z-extent of boss
// centre the magnets at the vertical midpoint of the frame interior
EDGE_MAG_Z_CENT  = (BACK_THICK + FRAME_H) / 2;         // 7.75
EDGE_MAG_BOSS_ZL = EDGE_MAG_Z_CENT - EDGE_MAG_BOSS_H/2;
EDGE_MAG_BOSS_ZH = EDGE_MAG_Z_CENT + EDGE_MAG_BOSS_H/2;

BACK_MAG_INSET   = 8;       // from tile corner, diagonal (BACK_MAGNETS = true)

// ----- back ventilation slots -----
BACK_VENT_W      = 3;
BACK_VENT_L      = 30;
BACK_VENT_ROWS   = 3;

// ----- diffuser rim (press-fit into frame interior opening) -----
// Diffuser is a 100 × 100 × DIFFUSER_THICK panel. On its back face, a
// continuous downward rim matches the frame's interior opening, creating
// a press-fit jar-lid closure. Light interference fit (negative
// clearance) gives a firm hold; bump to RIM_CLEAR = 0.05 if your printer
// over-extrudes.
RIM_CLEAR        = 0.20;     // per-side clearance (smaller = tighter)
RIM_DEPTH        = 3.0;      // how far the rim descends into the frame
RIM_T            = 1.2;      // rim wall thickness
DIFF_PULL_W      = 12;       // finger-pry slot on one edge
DIFF_PULL_D      = 1.2;
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

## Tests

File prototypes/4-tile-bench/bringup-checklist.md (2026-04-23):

# Bring-up checklist

Sequential verification plan. Each step assumes the previous ones passed. Stop and diagnose at the first failure — don't power on the next stage with a broken previous stage.

## Stage 0 — before powering anything

- [ ] All parts inventoried and counted against [`parts-list.md`](parts-list.md).
- [ ] 24 V PSU set-point confirmed on DMM **before** connecting any tile.
- [ ] 24 V PSU GND and master GND wired together; verified with DMM continuity.
- [ ] Reverse-polarity MOSFET (Q1) orientation verified on at least one tile before first power.
- [ ] Inrush: first tile's C1 (47 µF) is not yet connected — wire the chain tile-by-tile as you validate each stage.

## Stage 1 — single tile, no LEDs, no bus

- [ ] Connect tile #1 to 24 V PSU via its edge connector.
- [ ] Confirm Q1 does not heat (indicates correct polarity; reverse-polarity would dissipate rail power).
- [ ] Measure 5 V rail at MP1584 output: **4.95–5.05 V**. Trim pot if using module.
- [ ] Measure buck ripple: target **< 50 mV pk-pk** on 20 MHz scope.
- [ ] Disconnect PSU and measure current-limited short between 5 V and GND to verify polyfuse trips within a few seconds (re-settable).

## Stage 2 — MCU alive

- [ ] Flash CH32V003 with a minimal blink firmware (toggle PA1 at 1 Hz, no LEDs attached yet).
- [ ] Verify SWIO programming at 3 V PD1 level (WCH-LinkE handles this).
- [ ] Scope PA1 — clean 1 Hz square wave at 5 V logic.
- [ ] Run the "read UID" firmware; log 64-bit UID over SWD console. Save the UID for the four tiles so we know which chip is which during bench tests.

## Stage 3 — LEDs alive, local frame

- [ ] Attach the 25-LED SK6812 chain to tile #1.
- [ ] Flash "rainbow" firmware that cycles the chain with no bus.
- [ ] Measure 5 V rail at full white: **must not dip below 4.8 V**. If it does, buck is undersized or input rail is sagging.
- [ ] Thermal check: surface temperature of buck chip and LEDs after 10 minutes of full white. Target < 70 °C on the buck, < 60 °C on the LED PCB.
- [ ] Repeat stages 1–3 for tiles #2, #3, #4 independently before chaining.

## Stage 4 — RS-485 point-to-point (master ↔ tile #1)

- [ ] Wire only tile #1 to the master. Populate 120 Ω termination and 680 Ω biasing on master; populate 120 Ω on tile #1 (its the "far end" for this sub-test).
- [ ] Master firmware: send a `PING` packet every 100 ms at 1 Mbps. Tile #1 echoes back.
- [ ] Scope A and B on the tile side. Differential swing should be **≥ 1.5 V pk-pk**; common mode steady near V+/2.
- [ ] Run ping loop for 10 minutes. Count errors. Target: **zero**.

## Stage 5 — discovery on single tile

- [ ] Master runs binary-tree UID search; verify it returns the UID saved in stage 2.
- [ ] Master assigns address 1 to tile #1. Tile #1 responds only to address 1 and 0xFF thereafter.
- [ ] Power-cycle tile. Re-enumerate. Verify same UID, same address assignment (deterministic if master uses UID-ordered assignment).

## Stage 6 — chain of 2

- [ ] Remove tile #1's termination (it's no longer the endpoint).
- [ ] Wire tile #2 into the chain; populate 120 Ω on tile #2.
- [ ] Verify both tiles enumerate. UIDs match those saved in stage 2.
- [ ] Measure 24 V rail at tile #2's input: target **≥ 23.5 V** under full LED load on both tiles.
- [ ] Verify no regression in ping error rate after 10-minute soak.

## Stage 7 — chain of 4 (the goal)

- [ ] Wire tiles #3 and #4. Termination moves to tile #4.
- [ ] All four tiles enumerate within 1 second from cold boot. Repeat 10 times.
- [ ] Frame push: master writes 25 pixels to each tile, broadcasts `LATCH`, measures round-trip time. Target **≤ 20 ms per frame**.
- [ ] Sustained 30 fps animation for 30 minutes. Log errors. Target: **zero dropped frames**.
- [ ] Measure 24 V at tile #4: target **≥ 23.0 V** under full-white worst case.
- [ ] Thermal soak all four tiles at full white for 30 minutes; all surfaces < 60 °C.

## Stage 8 — fault injection

- [ ] With all four running, short the 5 V rail on tile #2 (deliberately, with a test lead).
- [ ] Verify only tile #2's polyfuse trips; tiles #1, #3, #4 continue operating.
- [ ] Allow polyfuse to cool (~30 s), verify tile #2 recovers after reset.
- [ ] Disconnect tile #3 mid-operation (pull the edge connector). Verify:
  - [ ] Tiles #1 and #2 continue operating.
  - [ ] Master detects tile #3 and #4 are missing on next poll.
  - [ ] Reconnect; re-enumerate finds them again.

## Stage 9 — stretch goals (nice to have before PCB)

- [ ] Push bit rate to 2.5 Mbps; verify still clean on 4-tile chain.
- [ ] Measure idle current per tile (just the MCU + transceiver, LEDs off): target < 30 mA @ 24 V.
- [ ] EMI sniff with a near-field probe on the LED data line and RS-485 A/B. Note any worrying peaks >100 MHz for future PCB shielding.

## Exit criteria

All stages 0–8 passing and repeatable across two cold-start cycles means the design is validated and we can move to PCB layout. Anything failing is a gate — fix before continuing.

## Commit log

2026-04-23 Initial structure: architecture draft, submodules, placeholder directories
    Captures the per-tile MCU concept with honest open questions attached
    rather than pretending the design is settled. Adds OpenSCAD submodules
    for mechanical modelling.
2026-04-23 Commit v1: RS-485 + 24V backbone + palindromic edge connector
    Replaces the original parallel-bus sketch with a design grounded in
    proven industrial practice. Power moves to a 24V backbone with per-tile
    buck converters (solves the 48A-through-pogo-pins problem). Signal
    moves to RS-485 half-duplex (differential, 40+ years of DMX/industrial
    use). Edge connector becomes 8-pin palindromic so tiles rotate freely
    while every signal has a redundant pin.
    Adds prototypes/4-tile-bench/ with schematic, detailed parts list,
    and a sequential bring-up checklist for the first physical build.
2026-04-23 Three-part tile mechanical model + verified sourcing links
    Tile enclosure is now a proper three-part print: frame (main body with
    corner bosses, magnet pockets, pogo pin holes, PCB screw bosses, back-cap
    snap ledge), interchangeable diffuser panel (drops into front lip,
    retained by clips, pull-out slot), and removable vented back cap.
    Edge connector geometry matches the 8-pin palindromic spec from
    architecture.md: 8 through-holes at 2.54 mm pitch with flange counterbores
    sized for standard double-ended pogo pins. Parametric fallback to a 1x8
    pin header slot for the bench prototype (CONN_TYPE="header").
    Sourcing guide gets real AliExpress and UK/EU distributor links from
    web searches, plus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
    [tile.scad]
2026-04-23 Move magnets from back face to edges for tile-to-tile attachment
    The original design put magnets on the tile back face, which is only
    useful for sticking the assembly to a metal wall. Tiles mate edge-to-edge
    on a wall, so the magnets that hold neighbours together need to be in
    the side walls opposite matching positions on the adjacent tile.
    Adds edge magnet pockets on each populated edge, cut from the outer
    face and backed by a reinforcement boss in the back half of the tile
    interior (so the PCB doesn't need cutouts). Polarity follows a CCW-
    handed rule that makes any edge pair mate correctly in any rotation.
    Assembly view renders ghost magnets colour-coded red (N) / blue (S)
    as an install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
    [tile.scad]
2026-04-23 Two-piece tile: integrated back, full-size diffuser with rim, 4 edges populated
    Collapses back cap into an integrated rear wall (vented), so per-tile
    print count drops from 3 pieces to 2. Diffuser becomes a full 100x100
    panel covering the entire front face edge-to-edge — when tiles sit
    adjacent, glow runs continuously across the seam with no frame lip
    breaking the line.
    Diffuser retention is now a continuous press-fit rim on the underside
    (jar-lid closure) instead of discrete flex clips. No fatigue points, no
    snap bumps, printable without support. Finger-pry notch for removal.
    Edge connector populated on all FOUR edges by default so the frame is
    ready for v2 free-form mesh. Pogo pins sho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
    [tile.scad]
2026-04-23 Fit analysis: layout plan, corner-boss fix, optional light guide
    Corner bosses now stop at z = PCB_BOTTOM_Z (= 6 mm) instead of
    protruding through the PCB plane, so the PCB sits flat on top of
    them without requiring corner cutouts — all 25 LED positions in
    the 5x5 grid are preserved. Boss dimension reduced from 14 to 10 mm
    to open interior space and let the M2 screw sit 2 mm from the PCB
    corner (was 1 mm — too close).
    Adds an optional third printable part: a 5x5 pixel-grid light
    guide that sits between the PCB and the diffuser for a distinct-
    pixel look. No retention features; held by PCB below + diffuser
    rim above. Core 2-part design (frame + diffuser) unchanged.
    hardware/tile/layout-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
    [tile.scad]
2026-04-23 Tile is a lighting element, not a display: 9 LEDs + central support
    Drops the LED count from 25 to 9 (3x3 grid, 30 mm pitch). The tile is
    one colour cell in the system, not a pixel display — 9 SK6812 RGBW gives
    ~45 lumens of diffused ambient glow with the diffuser doing the blending.
    Smaller power footprint drops the system PSU from 15 A to 4 A, tile BOM
    from ~£8 to ~£5, and the 32-tile system cost from ~£344 to ~£237.
    Retains the single-PCB design — LEDs on the top face facing the diffuser,
    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
    [tile.scad]
2026-04-23 No custom PCB: LED cradles + MCU pocket replace corner bosses
    The tile's electronics are now all pre-made drop-ins. The frame prints
    9 LED-module cradles (15 x 15 mm bays with 1.2 mm retention lip) in the
    3x3 grid positions, plus a 26 x 20 mm retention pocket in the -X,-Y
    corner for any small MCU dev board (XIAO ESP32-C3, CH32V003 breakout,
    RP2040-Zero, etc.). Buck converter and RS-485 transceiver breakouts
    float in the gaps between cradles with double-sided tape.
    Removed:
    - Corner bosses (frame_corner_bosses) — no PCB to mount
    - Centre support pillar (frame_centre_pillar) — no PCB to support
    - PCB screw holes (frame_pcb_screw_holes)
    - Back-face magnet pockets (frame_back_magnet_pockets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
    [tile.scad]
2026-04-24 Move diffuser + light guide beside the frame in assembly view
    The exploded stack-on-Z view hid the diffuser behind the camera angle
    and made the light guide hard to read. All three printable parts now
    sit in a plan-view layout: frame at the origin, diffuser 20 mm to the
    right on +X, light guide 20 mm above on +Y. All three render visible
    in a single image, each in its own footprint.
    RENDER="frame"|"diffuser"|"light_guide" still exports each part to its
    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
    [tile.scad]
